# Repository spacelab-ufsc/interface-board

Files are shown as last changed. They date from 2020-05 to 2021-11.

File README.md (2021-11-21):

<h1 align="center">
	Interstage Interface Panels
	<br>
</h1>

<h4 align="center">Interface Panels designed and developed by SpaceLab.</h4>

<p align="center">
	<a href="https://github.com/spacelab-ufsc/spacelab#versioning">
		
	</a>
	<a href="https://github.com/spacelab-ufsc/interface-board/releases">
		
	</a>
	<a href="https://github.com/spacelab-ufsc/interface-board/releases">
		
	</a>
	<a href="https://github.com/spacelab-ufsc/interface-board/commits/master">
		
	</a>
	<a href="https://github.com/spacelab-ufsc/interface-board/issues">
		
	</a>
	<a href="https://github.com/spacelab-ufsc/interface-board/graphs/contributors">
		
	</a>
</p>

<p align="center">
  	<a href="#overview">Overview</a> •
  	<a href="#license">License</a> •
  	<a href="#notes">Notes</a>
</p>

<p align="center">
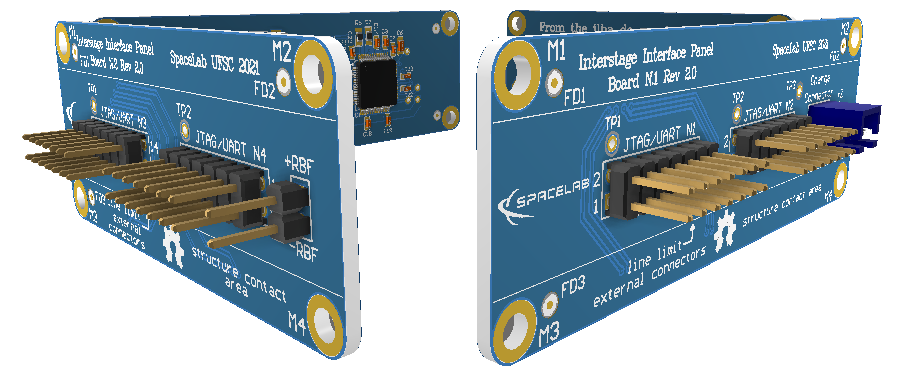
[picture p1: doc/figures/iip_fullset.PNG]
    
</p>

## Overview

Interstage Interface Panels (IIP) are vertical mounted PCBs designed to give external access to the modules inside of a 2U or 3U CubeSat during final assembly, integration and testing. IIP is composed by 4 different boards, the complete set allows for the nanosatellite to be charged, programed and debugged.

## Repository Organization
	- doc: IIP documentation.
	- hardware: IIP hardware project (sources and outputs).

## Releases

The IIP hardware releases are synchronized in order to garantee compatibility. Refer to the [documentation](https://github.com/spacelab-ufsc/interface-board/tree/master/doc) for compatibility notes.

## License

This project is licensed under CERN Open Hardware License (version 2). The documentation is licensed under Creative Commons Attribution-ShareAlike 4.0 International (CC BY-SA 4.0).

## Notes

More info about the SpaceLab: [GitHub](https://github.com/spacelab-ufsc/spacelab) and [Website](https://spacelab.ufsc.br/en/home/).

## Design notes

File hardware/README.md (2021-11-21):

<h1 align="center">
	IIP HARDWARE
	<br>
</h1>

<h4 align="center">Interface panels hardware project (sources and outputs).</h4>

<p align="center">
    <a href="https://github.com/spacelab-ufsc/spacelab#versioning">
        
    </a>
    <a href="https://github.com/spacelab-ufsc/interface-board/releases">
        
    </a>
    <a href="https://github.com/spacelab-ufsc/interface-board/releases">
        
    </a>
    <a href="https://github.com/spacelab-ufsc/interface-board/commits/master">
        
    </a>
    <a href="https://github.com/spacelab-ufsc/interface-board/issues">
        
    </a>
    <a href="">
        
    </a>
    <a href="#license">
        
    </a>
</p>

<p align="center">
  	<a href="#overview">Overview</a> •
  	<a href="#hardware-architecture-diagram">Architecture</a> •
  	<a href="#development">Development</a> •
  	<a href="#version">Version</a> •
  	<a href="#license">License</a> •
  	<a href="#references">References</a>
</p>

## Overview

IIP is composed of 4 pcbs with the main components:

### Nº1 board (1_iip_charge):

<p align="center">
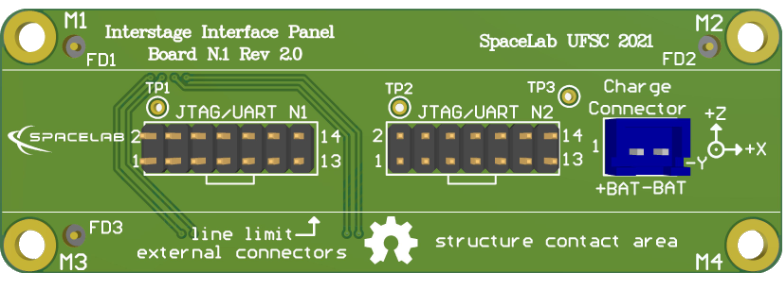
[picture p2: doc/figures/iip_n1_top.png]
	
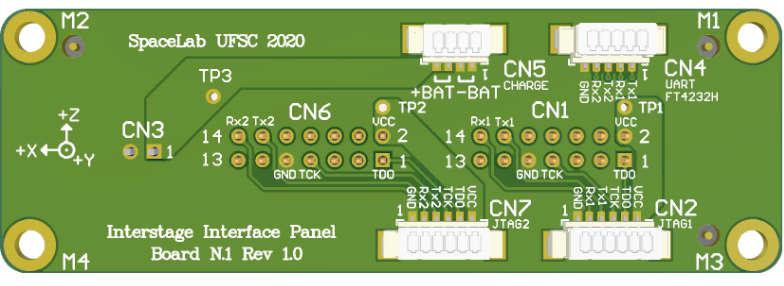
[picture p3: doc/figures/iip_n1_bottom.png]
	
</p>

* Two 7x2 position pin headers for JTAG;
* One JST 2 position header for charging batteries;
* Two 6 pin PicoBlade for internal modules connection;
* One 5 pin PicoBlade for interfacing Nº1 Board to FT4232H present on Nº3 board;
* One 4 pin PicoBlade for battery charge connection to EPS module;

### Nº2 board (2_iip_rbf):

<p align="center">
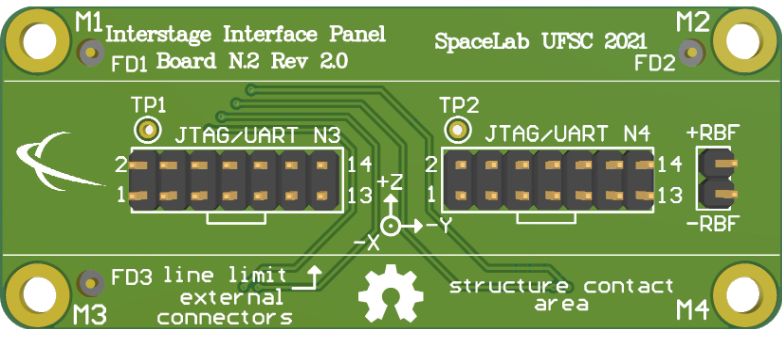
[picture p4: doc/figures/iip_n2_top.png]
	
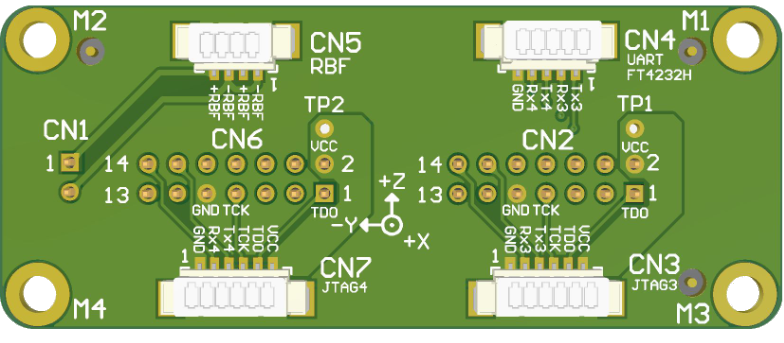
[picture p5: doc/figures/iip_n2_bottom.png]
	
</p>

* Two 7x2 position Pin Headers for JTAG;
* One 2x1 position pin header for Remove Before Flight switch;
* Two 6 pin PicoBlade for internal modules connection;
* One 5 pin PicoBlade for interfacing Nº2 Board to FT4232H present on Nº3 board;
* One 4 pin PicoBlade for RBF switch connection to EPS module;

### Nº3 board (3_iip_QuadUART):

<p align="center">
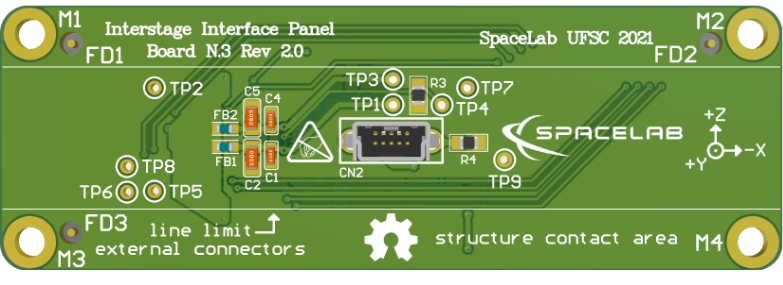
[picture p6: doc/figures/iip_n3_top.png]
	
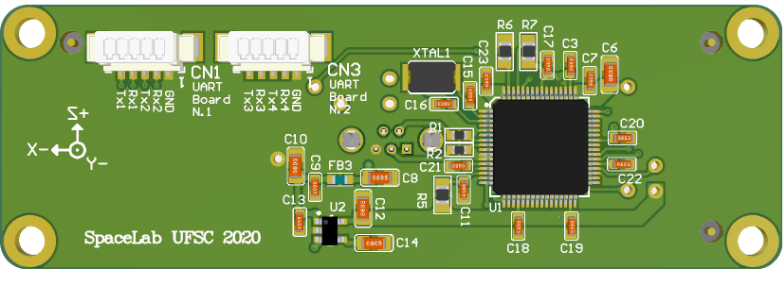
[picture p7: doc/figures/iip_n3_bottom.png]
	
</p>

* One FT4232HL-REEL IC for four quad channel USB to UART conversion;
* One Vertical mini B USB 2.0 port for quad UART channel debbuging;
* Two 5 pin PicoBlade for interfacing boards Nº1 and Nº2;

### Nº4 board (4_iip):

#### Closure variant

<p align="center">
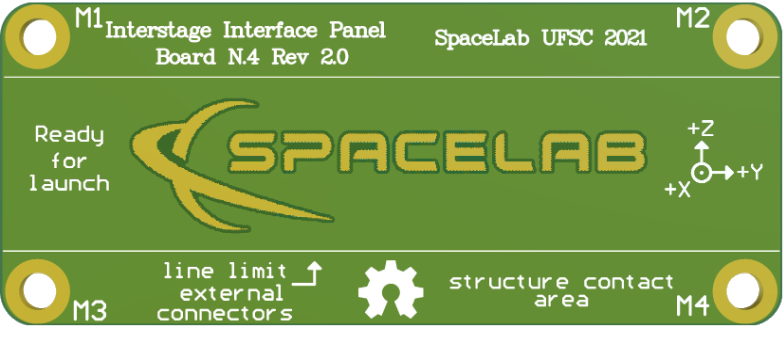
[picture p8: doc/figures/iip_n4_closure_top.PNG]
	
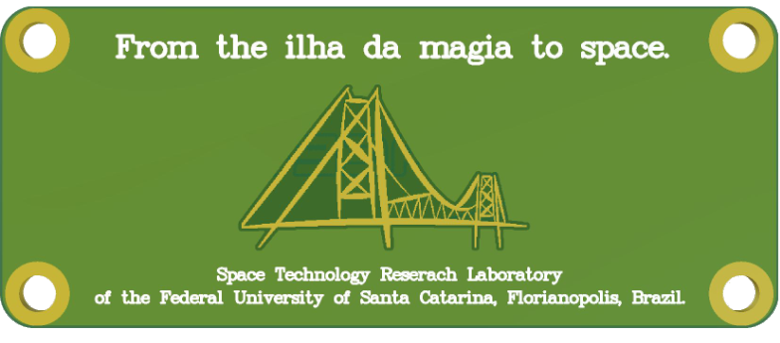
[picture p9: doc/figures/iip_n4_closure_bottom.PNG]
	
</p>

* Empty PCB to close the open side of the 2U/3U CubeSat structure with some easter eggs;

#### Camera variant

<p align="center">
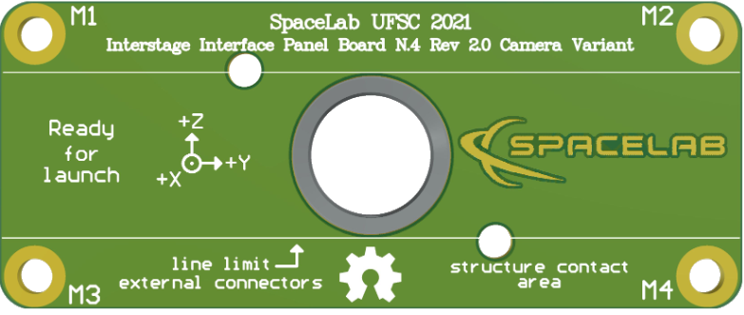
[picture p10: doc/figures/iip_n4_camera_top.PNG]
	
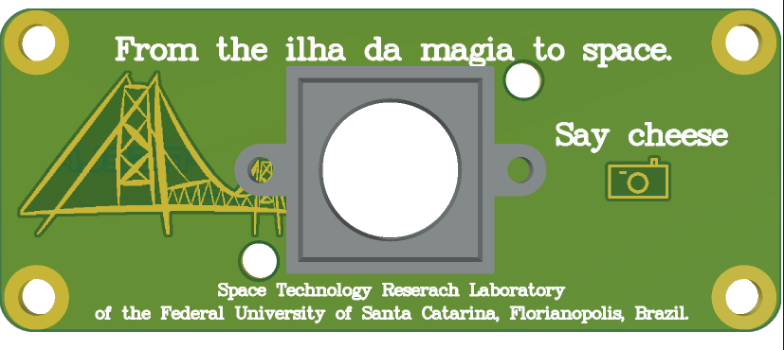
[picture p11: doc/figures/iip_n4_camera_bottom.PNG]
	
</p>

* Hole mount for a M12 lens camera;

> NOTE: The dimensions for the mouting holes follow a old [board breakout design](https://www.google.com/url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), they are still to be tested.

## Hardware architecture diagram

<p align="center">
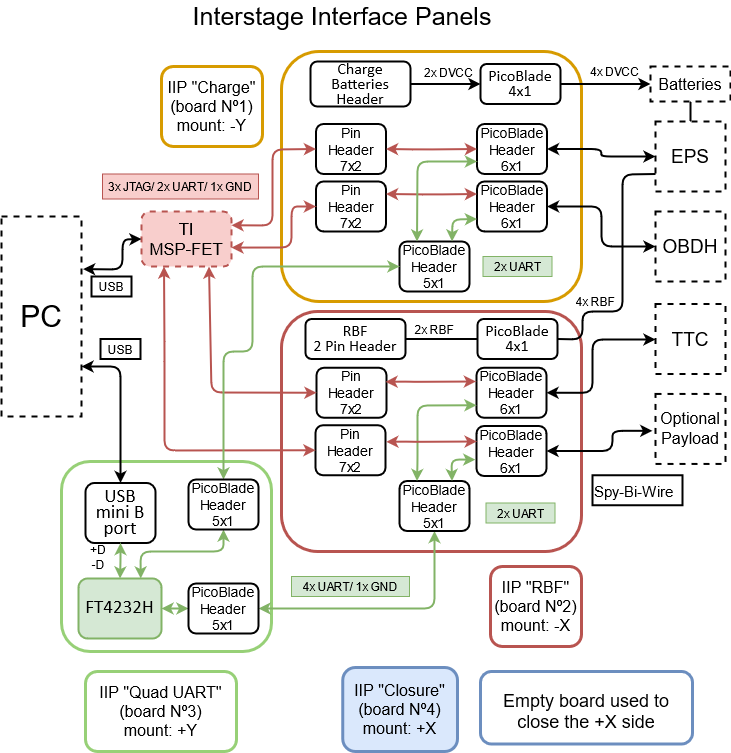
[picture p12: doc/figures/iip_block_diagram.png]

</p>

> This image refers to the v2.0 release.

## Development

#### Manufacture

The folder [fabrication](https://github.com/spacelab-ufsc/interface-board/tree/master/hardware/fabrication) contain 3 "ready to go" files: the gerbers and nc_drills for manufacturing the board, the BOM with all required components, and the pick_place file for automated assembly for each iip board. Additional files are avaliable in the [outputs](https://github.com/spacelab-ufsc/interface-board/tree/master/hardware/outputs) folder, which contain several useful files and documents, such as: 3D models, bill of materials, schematics, layout prints, and draftsman.

## Version

Refer to the [releases](https://github.com/spacelab-ufsc/interface-board/releases) page.

## License

The hardware project of IIP is licensed under CERN Open Hardware License (version 2).

## References

* [NanoUtil Interstage - GOMspace](https://gomspace.com/UserFiles/Subsystems/datasheet/gs-ds-nanoutil-interstage-12.pdf)
* [Quad Serial project from Felipe Navarro](https://github.com/PY1CX/Quad-Serial)
* [FT4232H QUAD HIGH SPEED USB TO MULTIPURPOSE UART/MPSSE IC Datasheet Version 2.6](https://www.ftdichip.com/Support/Documents/DataSheets/ICs/DS_FT4232H)

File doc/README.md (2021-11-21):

<h1 align="center">
	IIP Documentation
	<br>
</h1>

<h4 align="center">Documentation of the Interstage Interface Panels.</h4>

<p align="center">
    <a href="https://github.com/spacelab-ufsc/spacelab#versioning">
        
    </a>
    <a href="https://github.com/spacelab-ufsc/interface-board/releases">
        
    </a>
    <a href="https://github.com/spacelab-ufsc/interface-board/releases">
        
    </a>
    <a href="https://github.com/spacelab-ufsc/interface-board/commits/master">
        
    </a>
    <a href="https://github.com/spacelab-ufsc/interface-board/issues">
    	
	</a>
	<a href="">
		
	</a>
    <a href="#license">
        
    </a>
</p>

<p align="center">
  	<a href="#dependencies">Dependencies</a> •
  	<a href="#generating-the-pdf-file">Generating the PDF file</a> •
  	<a href="#license">License</a> •
  	<a href="#notes">Notes</a>
</p>

## Dependencies

* ```latexmk```
* ```texlive-epstopdf```

## Generating the PDF file

```
make
```

## License

The documentation is licensed under Creative Commons Attribution-ShareAlike 4.0 International (CC BY-SA 4.0).

## Notes

More info about the SpaceLab: [GitHub](https://github.com/spacelab-ufsc/spacelab) and [Website](https://spacelab.ufsc.br/en/home/).

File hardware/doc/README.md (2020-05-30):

### Documentation of the Semi USB variant of Interface Board 2.0

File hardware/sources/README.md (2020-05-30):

### Shematic and PCB files of the Semi USB variant of Interface Board 2.0

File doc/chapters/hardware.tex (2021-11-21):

%
% hardware.tex
%
% Copyright © 2021 by Universidade Federal de Santa Catarina.
%
% Documentation of Interstage Interface Panels
%
% This work is licensed under the Creative Commons Attribution-ShareAlike 4.0
% International License. To view a copy of this license,
% visit http://creativecommons.org/licenses/by-sa/4.0/.
%

%
% \brief Hardware chapter.
%
% \author Yan Castro de Azeredo <yan.azeredo@spacelab.ufsc.br>
%
% \institution Universidade Federal de Santa Catarina (UFSC)
%
% \version 2.0.0
%
% \date 05/07/21 (DD/MM/YY)
%
% \note Credits to Gabriel Mariano Marcelino <gabriel.marcelino@spacelab.ufsc.br> for the creation of the SpaceLab Template
%

\chapter{Hardware} \label{ch:hardware}

IIP is designed to be mouted vertically on the sides of a 2U or 3U CubeSat structure and provide all the minimal features for AIT. In the following sections, the hardware design, external and internal connectors, the FT4232H IC and test points are described in detail. On \autoref{fig:iip-all-boards} is displayed top and bottom PCB prints of all boards.

\begin{figure}[!h]
\centering     %%% not \center
\subfigure[IIP Nº1 "Charge" top]{\label{fig:a}}
\subfigure[IIP Nº1 "Charge" bottom]{\label{fig:b}}
\subfigure[IIP Nº2 "RBF" top]{\label{fig:a}}
\subfigure[IIP Nº2 "RBF" bottom]{\label{fig:b}}
\subfigure[IIP Nº3 "Quad UART" top]{\label{fig:a}}
\subfigure[IIP Nº3 "Quad UART" bottom]{\label{fig:b}}
\subfigure[IIP Nº4 "Closure" variant top]{\label{fig:a}}
\subfigure[IIP Nº4 "Closure" variant bottom]{\label{fig:b}}
\subfigure[IIP Nº4 "Camera" variant top]{\label{fig:a}}
\subfigure[IIP Nº4 "Camera" variant bottom]{\label{fig:b}}
\caption{IIP fullset of boards.}
\label{fig:iip-all-boards}
\end{figure}

\section{Hardware Design}

To be low cost, IIP has the default two layer stackup, HASL finish, 0.3mm minimal hole size, 2.54mm miminal track width and no controled impedance. While for fast USB communication it is recommended a controled impedance of 90 ohms, as exposed in USB Hardware Design Guidelines for FTDI ICs \cite{ftdi-usb-hardware-guidelines}, IIP Nº3 board is not meant to operate with high speed signals. The hightest baund rate for UART log messages for debbuging purposes is expected to be 115200 bps, this parameter is defined for SpaceLab's core modules. Although not a serious concern, the tracks used for the mini USB type B connector to the FT4232H IC were made the shortest possible and most of the guidelines of FTDI were followed.

Components size and positioning were decided for conforming with the CubeSat 2U standard of maximum connector height on the sides of the P-POD structure \cite{p-pod-user-guide} and to a specific project scenario using SpaceLab's core modules for the FloripaSat-2 mission \cite{floripasat2}.

\section{External and internal connectors}

In this section all external and internal connectors are exposed in detail.

\subsection{JTAG/UART Pin Headers}

There are four 14 pin headers (2.54mm pitch) on IIP for JTAG and UART usage, two are present in Nº1 board and the other two in Nº2 board, they can be seem on the two figures \ref{fig:iip-jtag-n1-n2-pin-headers} and \ref{fig:iip-jtag-n3-n4-pin-headers}. These headers were choosen to be used with MSP-FET tool and its standard cable connector. Their pionout is showed on table \ref{tab:jtag-headers-pinout}.

\begin{table}[!h]
    \centering
    \begin{tabular}{cllll}
        \toprule[1.5pt]
        \textit{Pin [A-B]} & \textit{Row A} & \textit{Row B} \\
        \midrule
        1-2                & TDO\_TDI       & VCC\_3V3       \\
        3-4                & -              & -              \\
        5-6                & -              & -              \\
        7-8                & TCK            & -              \\
        9-10               & GND            & -              \\
        11-12              & -              & UART\_TX       \\
        13-14              & -              & UART\_RX       \\
        \bottomrule[1.5pt]
    \end{tabular}
    \caption{JTAG pin headers pinout.}
    \label{tab:jtag-headers-pinout}
\end{table}

\begin{figure}[!ht]
\centering
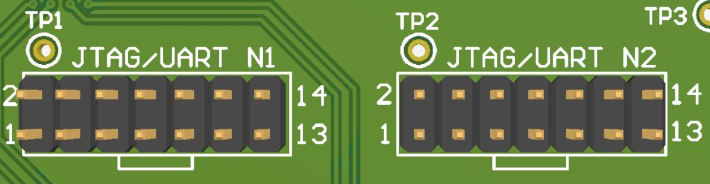
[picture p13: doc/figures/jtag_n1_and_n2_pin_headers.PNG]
    
    \caption{IIP Nº1 JTAG pin headers.}
    \label{fig:iip-jtag-n1-n2-pin-headers}
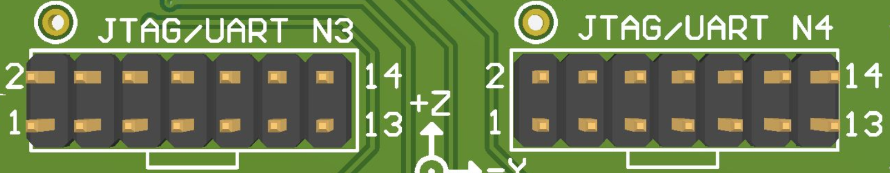
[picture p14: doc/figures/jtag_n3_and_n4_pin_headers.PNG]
    
    \caption{IIP Nº2 JTAG pin headers.}
	\label{fig:iip-jtag-n3-n4-pin-headers}
\end{figure}

Internally these pin headers are interfaced via PicoBlades to be connected to the four modules inside the CubeSat. As can be seen in the block diagram figure \ref{fig:block-diagram} present on the overview chapter, each one of these PicoBlades is assigned to a specific module, they are showed in figures \ref{fig:iip-jtag-n1-n2-picoblades} and \ref{fig:iip-jtag-n3-n4-picoblades}.

\begin{figure}[!ht]
\centering
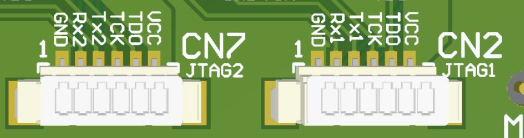
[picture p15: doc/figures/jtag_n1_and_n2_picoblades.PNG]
    
    \caption{IIP Nº1 JTAG PicoBlades.}
    \label{fig:iip-jtag-n1-n2-picoblades}
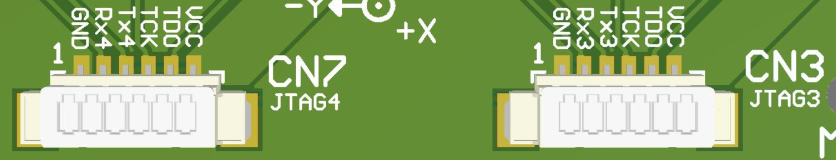
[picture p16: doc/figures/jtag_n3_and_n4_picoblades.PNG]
    
    \caption{IIP Nº2 JTAG PicoBlades.}
	\label{fig:iip-jtag-n3-n4-picoblades}
\end{figure}

\subsection{Charge Header}

On board Nº1 there is a JST XH 2 position header [B2B-XH-A-M(LF)(SN)] for charging batteries of the CubeSat, it can be seen in figure \ref{fig:iip-charge-header}. The component can suport up to 3000mA of current, but in practice it will be used with less than 1500mA. The internal 4 pin PicoBlade connector showed in figure \ref{fig:iip-charge-picoblade} is to be connected to the EPS module to make the interconnection for the JST header. The charge header also provides a detent lock for fastening and avoid mistankenly reverse connection.

\begin{figure}[!ht]
\centering
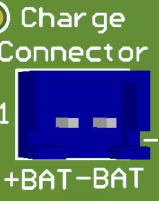
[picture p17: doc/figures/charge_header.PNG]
    
    \caption{IIP Nº1 charge header.}
	\label{fig:iip-charge-header}
\end{figure}

\begin{figure}[!ht]
\centering
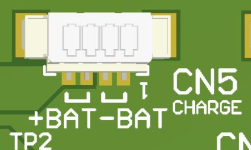
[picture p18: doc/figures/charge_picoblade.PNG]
    
    \caption{IIP Nº1 charge PicoBlade.}
	\label{fig:iip-charge-picoblade}
\end{figure}

\subsection{RBF Pin Header}

The Remove Before Flight pin header is located on board Nº2, see figure \ref{fig:iip-rbf-pin-header}. The choice of its location was according to the CubeSat Design Specification from Cal Poly SLO \cite{cubesat-design-specification} that required the RBF pin to be located on the X plane of the P-POD. This ensures that the CubeSat subsystems will be powered off on test phase using a simple jumper wire conecting the pins, even with kill-swithes already enabled to do this fuctionality by been pressed againts the spring mechanism. The interconnection between the header and the EPS module is done by a internal 4 pin PicoBlade, showed in figure \ref{fig:iip-rbf-picoblade}.

\begin{figure}[!ht]
\centering
    
    \caption{IIP Nº2 RBF pin header.}
	\label{fig:iip-rbf-pin-header}
\end{figure}

\begin{figure}[!ht]
\centering
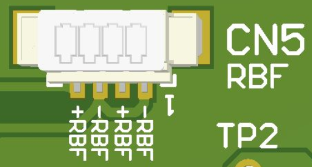
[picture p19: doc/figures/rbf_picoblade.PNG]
    
    \caption{IIP Nº2 RBF PicoBlade.}
	\label{fig:iip-rbf-picoblade}
\end{figure}

\subsection{Mini USB Type B Port}

On Nº3 board there is a vertical mini USB type B 2.0 port (651005136421) to be used for UART debbuging, the connector is seen on figure \ref{fig:iip-usb-port}. This is done though the FT4232HL-REEL IC and its subcircuitry located on the bottom side of the PCB, a better vision is showed on figure \ref{fig:iip-usb-circuitry}. The circuit is self powered by the USB cable, not requiring any external power supply.

There are two internal 5 pin PicoBlade connectors that connects with boards Nº1 and Nº2 to acquire the UART log data from the modules, these components are showed on figure \ref{fig:iip-n3-picoblades}. The other Picoblades that makes this interconnection between interface panels are seen in figures \ref{fig:iip-n1-uart-picoblade} and \ref{fig:iip-n2-uart-picoblade}, for Nº1 and Nº2 boards respectively.

\begin{figure}[!ht]
\centering
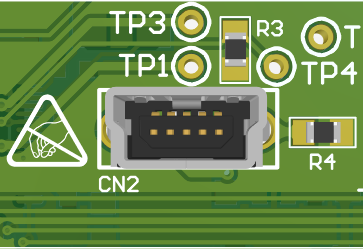
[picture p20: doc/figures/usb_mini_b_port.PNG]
    
    \caption{IIP Nº3 mini USB type B port.}
	\label{fig:iip-usb-port}
\end{figure}

\begin{figure}[!ht]
\centering
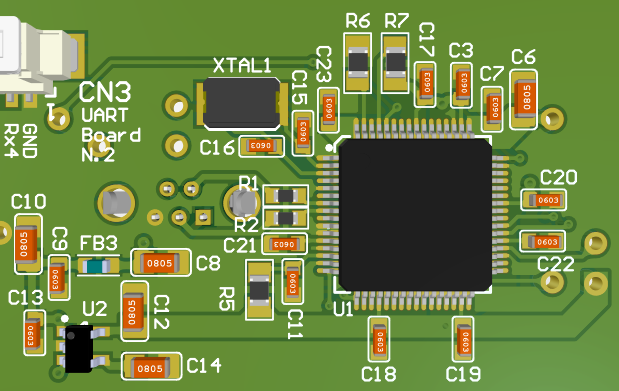
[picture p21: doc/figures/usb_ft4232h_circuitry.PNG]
    
    \caption{IIP Nº3 USB auxiliary circuitry.}
	\label{fig:iip-usb-circuitry}
\end{figure}

\begin{figure}[!ht]
\centering
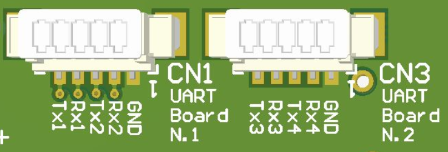
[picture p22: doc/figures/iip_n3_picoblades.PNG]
    
    \caption{IIP Nº3 UART PicoBlades.}
    \label{fig:iip-n3-picoblades}
\end{figure}

\begin{figure}[!ht]
\centering
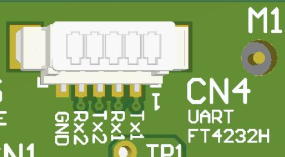
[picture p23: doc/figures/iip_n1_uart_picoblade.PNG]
    
    \caption{IIP Nº1 UART PicoBlade.}
    \label{fig:iip-n1-uart-picoblade}
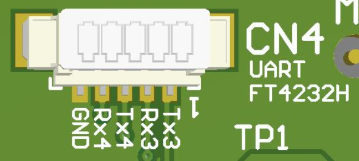
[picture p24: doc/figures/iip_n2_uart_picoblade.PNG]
     
    \caption{IIP Nº2 UART PicoBlade.}
    \label{fig:iip-n2-uart-picoblade}
\end{figure}

\section{FT4232H IC}

For UART to USB conversion the FT4232HL-REEL IC from FTDI \cite{ftdi-ft4232h-datasheet} was chossen for enabling the debbuging though log messages for 4 independent modules. The REEL form factor was decided to be easier to be soldered manually if necessary. The IC gives flexibility to have an integrated UART to USB conversion in the inferface of IIP, not needing the use of a external device like the FT232. The component and its auxiliary subcircuitry can be seen on figure \ref{fig:iip-usb-circuitry}.

\section{Test Points}

On the three boards of IIP there are some test points that can be easily acessed from the front side of the panels. Others that are present on the "structure contact area" will not be available when the interface is assembled on the 2U CubeSat structure, see the PCBs top and bottom prints on figures figures \ref{fig:iip-all-boards-top-bottom-1} to \ref{fig:iip-all-boards-top-bottom-2}. The reason for this is that the metal frame of the structure will be at the front blocking the access, referer to chapter \ref{ch:board-assembly} for more details. Next is presented the tables of the test points labels and their description of the boards Nº1: \ref{tab:iip-n1-testpoints}, Nº2: \ref{tab:iip-n2-testpoints} and Nº3: \ref{tab:iip-n3-testpoints}.

\begin{table}[!h]
    \centering
    \begin{tabular}{cllll}
        \toprule[1.5pt]
        \textit{Label} & \textit{Description} \\
        \midrule
        TP1                & JTAG 1 3V3 power\\
        TP2                & JTAG 2 3V3 power\\
        TP3                & Battery charge header positive polarity \\
        \bottomrule[1.5pt]
    \end{tabular}
    \caption{IIP Nº1 board test points.}
    \label{tab:iip-n1-testpoints}
\end{table}

\begin{table}[!h]
    \centering
    \begin{tabular}{cllll}
        \toprule[1.5pt]
        \textit{Label} & \textit{Description} \\
        \midrule
        TP1                & JTAG 3 3V3 power\\
        TP2                & JTAG 4 3V3 power\\
        \bottomrule[1.5pt]
    \end{tabular}
    \caption{IIP Nº2 board test points.}
    \label{tab:iip-n2-testpoints}
\end{table}

\begin{table}[!h]
    \centering
    \begin{tabular}{cllll}
        \toprule[1.5pt]
        \textit{Label} & \textit{Description} \\
        \midrule
        TP1                & (VPLL) 3V3 FT4232H power input. \\
        TP2                & (VREGOUT) 1V8 FT4232H internal power output. \\
        TP3                & (VPHY) 3V3 FT4232H power input. \\
        TP4                & (REF) Current reference for FT4232H. \\
        TP5                & (RESET\#) Reset input for FT4232H. \\
        TP6                & (VCCIO) I/O interface 3V3 power supply input. \\
        TP7                & (PWREN\#) Active low power-enable output. \\
        TP8                & (SUSPEND\#) Active low when USB is in suspend mode. \\
        TP9                & (GND) 0V ground input for FT4232H.\\
        \bottomrule[1.5pt]
    \end{tabular}
    \caption{IIP Nº3 board test points.}
    \label{tab:iip-n3-testpoints}
\end{table}

\section{M12 Camera Lens Mount}

On IIP Nº4 variant camera board has a center hole to serve as an opening for an M12 camera lens, the other two holes are for mouting the ArduCam MT9D111 rev.B. breakout board, as seen in \autoref{fig:arducam}. On \autoref{fig:n4-mec} is displayed the PCB mouting hole distances and sizes for the camera.

\begin{figure}[!ht]
  \centering
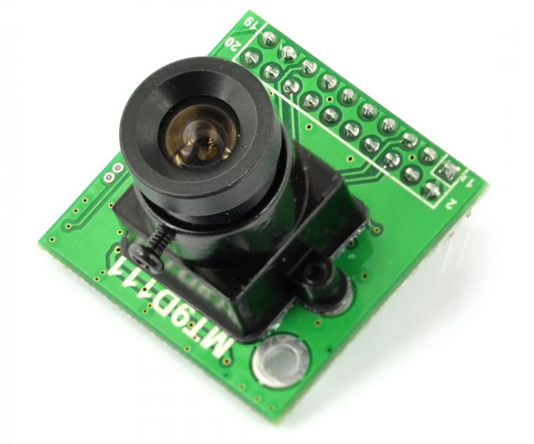
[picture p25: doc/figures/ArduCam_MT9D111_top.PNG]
    \subfigure[]{\label{fig:a}}
    \subfigure[]{\label{fig:b}}
    \caption{ArduCam MT9D111 rev.B.}
    \label{fig:arducam}
\end{figure}

\begin{figure}[!ht]
\centering
    
    \caption{IIP Nº4 Camera variant mechanical dimensions.}
    \label{fig:n4-mec}
\end{figure}

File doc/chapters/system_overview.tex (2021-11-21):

%
% system_overview.tex
%
% Copyright © 2021 by Universidade Federal de Santa Catarina.
%
% Documentation of Interstage Interface Panels
%
% This work is licensed under the Creative Commons Attribution-ShareAlike 4.0
% International License. To view a copy of this license,
% visit http://creativecommons.org/licenses/by-sa/4.0/.
%

%
% \brief System overview chapter.
%
% \author Yan Castro de Azeredo <yan.azeredo@spacelab.ufsc.br>
%
% \institution Universidade Federal de Santa Catarina (UFSC)
%
% \version 2.0.0
%
% \date 05/07/21 (DD/MM/YY)
%
% \note Credits to Gabriel Mariano Marcelino <gabriel.marcelino@spacelab.ufsc.br> for the creation of the SpaceLab Template
%

\chapter{System Overview} \label{ch:system-overview}

\section{Block Diagram}

On figure \ref{fig:block-diagram} is displayed the full system block diagram with external devices such as the MSP-FET and a personal computer (PC) during normal usage of IIP.
Up to four CubeSat modules can be acessed from its interfaces, been though the pin headers or the USB port. 
For the FloripaSat-2 mission, the core modules (EPS, OBDH and TTC) and a optional payload are already represented with their respective interconnections.
These connections are done internally with PicoBlade connectors, which are compatible with the mission's modules. 
The fourth board, labeled IIP Nº4, has two variants, one only serves as a closure for the side panel of the CubeSat structure, while the other features a central hole for a M12 camera lens and mouting holes for a breakout board.

\begin{figure}[!ht]
    \begin{center}
        
        \caption{IIP hardware block diagram.}
        \label{fig:block-diagram}
    \end{center}
\end{figure}

\section{Board Numeration}

Since the IIP is divided up to 4 boards, a numeration was adopted for better refering each PCB on this document. The numeration followed the criteria of the mounting sides determined by the cartesian axis of a Poly Picosatellite Orbital Deployer (P-POD) \cite{p-pod-user-guide}. Starting the numeration "Nº1" from the referenced -Y plane, the other boards are classified clock-wise that can be found on figure \ref{fig:iip-numeration}, each labeled axis can be better seen on \autoref{fig:iip-all-boards}. The boards also received names with their unique functionality, Nº1 board is also called "IIP Charge", Nº2 board the "IIP RBF", Nº3 board the "IIP Quad UART" and Nº4 board the "Closure" or "Camera" depending on its variant, these nominations are present on the PCBs source files.

\begin{figure}[!ht]
  \centering
    
    \caption{IIP Nº1 board.}
    
    \caption{IIP Nº2 board.}
    
    \caption{IIP Nº3 board.}
    
    \caption{IIP Nº4 closure variant board.}
    
    \caption{IIP Nº4 camera variant board.}
    \label{fig:iip-numeration}
\end{figure}

\section{Board Dimensions}

IIP is to be mouted vertically inside on the sides of a 2U/3U CubeSat structure, this makes de Nº1 and Nº3 boards having the same PCB dimensions because they are on the same X plane of reference, see figure \ref{fig:iip-n1-n3-dimensions}. 
The Nº2 and Nº4 board dimensions can be seen in figure \ref{fig:iip-n2-n4-dimensions}.
The "structure contact area" is the place where the metal frame of the CubeSat structure will be overlapping.
All other measurements important to integration and assembly are present in the draftsman PDF documents of each board are present on GitHub\cite{iip-draftsman}.
Refer to \autoref{sec:integration} for more details on mechenical integration of IIP.

\begin{figure}[!ht]
  \centering
    
    \caption{IIP Nº1 and Nº3 top dimensions.}
    \label{fig:iip-n1-n3-dimensions}
    
    \caption{IIP Nº2 and Nº4 board top dimensions.}
    \label{fig:iip-n2-n4-dimensions}
\end{figure}

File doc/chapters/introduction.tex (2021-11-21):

%
% introduction.tex
%
% Copyright © 2021 by Universidade Federal de Santa Catarina.
%
% Documentation of Interstage Interface Panels
%
% This work is licensed under the Creative Commons Attribution-ShareAlike 4.0
% International License. To view a copy of this license,
% visit http://creativecommons.org/licenses/by-sa/4.0/.
%

%
% \brief Introduction file.
%
% \author Yan Castro de Azeredo <yan.azeredo@spacelab.ufsc.br>
%
% \institution Universidade Federal de Santa Catarina (UFSC)
%
% \version 2.0.0
%
% \date 05/07/21 (DD/MM/YY)
%
% \note Credits to Gabriel Mariano Marcelino <gabriel.marcelino@spacelab.ufsc.br> for the creation of the SpaceLab Template
%

\chapter{Introduction} \label{ch:introduction}

The Interstage Interface Panels (IIP) are four vertical internally mounted Printed Circuit Boards (PCB\nomenclature{\textbf{PCB}}{\textit{Printed Circuit Board.}}) designed 
to give external access up to four modules inside of a 2U or 3U CubeSat during 
final assembly, integration and testing (AIT\nomenclature{\textbf{AIT}}{\textit{Assembly, integration and testing.}}) before launch.
The complete set of the boards allow the nanosatellite to be charged, programed and debugged. 
The usage of this project is taking into account the use of a MSP-FET: MSP430 Flash Emulation Tool from Texas Instruments for JTAG programing and debugging, UART debugging through a mini USB type B port interfacing the FT4232H USB bridge Integrated Circuit (IC\nomenclature{\textbf{IC}}{\textit{Integrated Circuit.}}) from FTDI, a JST XH header for charging internal batteries and a Remove Before Flight (RBF\nomenclature{\textbf{RBF}}{\textit{Remove Before Flight.}}) pin header.
One board variant features an opening for a M12 camera lens.  
These tools and methodology for testing are definied directly from the project main use on the FloripaSat-2 mission \cite{floripasat2} been done by SpaceLab UFSC.

\begin{figure}[!ht]
    \centering
    
    \caption{Interstage Interface Panel boards.}
    \label{iip-fullset}
  \end{figure}

All the project, source and documentation files are available freely on a GitHub repository \cite{interface-board-repo}.

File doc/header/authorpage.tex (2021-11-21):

%
% authorpage.tex
%
% Copyright © 2021 by Universidade Federal de Santa Catarina.
%
% Documentation of Interstage Interface Panels
%
% This work is licensed under the Creative Commons Attribution-ShareAlike 4.0
% International License. To view a copy of this license,
% visit http://creativecommons.org/licenses/by-sa/4.0/.
%

%
% \brief Author page.
%
% \author Yan Castro de Azeredo <yan.azeredo@spacelab.ufsc.br>
%
% \institution Universidade Federal de Santa Catarina (UFSC)
%
% \version 2.0.0
%
% \date 05/07/21 (DD/MM/YY)
%
% \note Credits to Gabriel Mariano Marcelino <gabriel.marcelino@spacelab.ufsc.br> for the creation of the SpaceLab Template
%

\thispagestyle{empty}

\begin{center}

\textbf{\thetitle}

\textit{July, 2021}

\vspace{1cm}

\textbf{Project Chief:}

Eduardo Augusto Bezerra

\vspace{1cm}

\textbf{Authors:}

Yan Castro de Azeredo <\href{mailto:yan.azeredo@spacelab.ufsc.br}{yan.azeredo@spacelab.ufsc.br}>\\
% Author 2 \\
% Author 3 \\

\vspace{1cm}

\textbf{Contributing Authors:}

André Martins Pio de Mattos <\href{mailto:andre.mattos@spacelab.ufsc.br}{andre.mattos@spacelab.ufsc.br}>\\
Gabriel Mariano Marcelino <\href{mailto:gabriel.marcelino@spacelab.ufsc.br}{gabriel.marcelino@spacelab.ufsc.br}>\\
% Author 3 \\

\vspace{1cm}

\textbf{Revision Control:}

\end{center}

\begin{table}[!ht]
    \begin{center}
        \begin{tabular}{cL{5cm}L{5.5cm}C{2cm}}
            \toprule[1.5pt]
            \textbf{Version} & \textbf{Author} & \textbf{Changes}    & \textbf{Date} \\
            \midrule
            0.1     & Yan C. de Azeredo    & Document creation   & 07/2020    \\
            1.0     & Yan C. de Azeredo    & First release       & 12/2020    \\
            2.0     & Yan C. de Azeredo    & Adding fourth interface board to project & 07/2021\\
                    &                          &                     &            \\
                    &                          &                     &            \\
            \bottomrule[1.5pt]
        \end{tabular}
    \end{center}
\end{table}

\vfill

\begin{figure}[!h]
	\begin{center}
		
	\end{center}
\end{figure}

\textcopyright\  2021 by Universidade Federal de Santa Catarina. Interstage Interface Panels. This work is licensed under the Creative Commons Attribution-ShareAlike 4.0 International License. To view a copy of this license, visit \href{http://creativecommons.org/licenses/by-sa/4.0/}{http://creativecommons.org/licenses/by-sa/4.0/}.

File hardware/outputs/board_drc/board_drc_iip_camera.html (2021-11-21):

Altium

# Design Rule Verification Report

Date: | | 7/4/2021
Time: | | 6:49:42 PM
Elapsed Time: | | 00:00:01
Filename: | | C:\Users\Yan Azeredo\Desktop\SpaceLab\interface-board\hardware\sources\4_iip_camera.PcbDoc

Warnings: | | 0
Rule Violations: | | 9

## Summary

Warnings | Count
Total | 0

Rule Violations | Count
Clearance Constraint (Gap=0.254mm) (All),(All) | 0
Clearance Constraint (Gap=0.254mm) (All),(All) | 0
Short-Circuit Constraint (Allowed=No) (All),(All) | 0
Un-Routed Net Constraint ( (All) ) | 0
Modified Polygon (Allow modified: No), (Allow shelved: No) | 0
Width Constraint (Min=0.254mm) (Max=0.254mm) (Preferred=0.254mm) (All) | 0
Width Constraint (Min=0.127mm) (Max=0.508mm) (Preferred=0.254mm) (All) | 0
Power Plane Connect Rule(Relief Connect )(Expansion=0.508mm) (Conductor Width=0.254mm) (Air Gap=0.254mm) (Entries=4) (All) | 0
Minimum Annular Ring (Minimum=0.254mm) (All) | 0
Minimum Annular Ring (Minimum=0.13mm) (All) | 0
Hole Size Constraint (Min=0.025mm) (Max=2.54mm) (All) | 0
Hole Size Constraint (Min=0.3mm) (Max=6.3mm) (All) | 1
Hole To Hole Clearance (Gap=0.54mm) (All),(All) | 0
Hole To Hole Clearance (Gap=0.254mm) (All),(All) | 0
Minimum Solder Mask Sliver (Gap=0.254mm) (All),(All) | 0
Minimum Solder Mask Sliver (Gap=0.2mm) (All),(All) | 3
Silk To Solder Mask (Clearance=0.15mm) (IsPad),(All) | 0
Silk To Solder Mask (Clearance=0.254mm) (IsPad),(All) | 0
Silk to Silk (Clearance=0.254mm) (All),(All) | 0
Net Antennae (Tolerance=0mm) (All) | 0
Board Clearance Constraint (Gap=0mm) (All) | 5
Board Clearance Constraint (Gap=0mm) (All) | 0
Height Constraint (Min=0mm) (Max=25.4mm) (Prefered=12.7mm) (All) | 0
Total | 9

Hole Size Constraint (Min=0.3mm) (Max=6.3mm) (All)

Hole Size Constraint: (14.5mm > 6.3mm) Pad Free-0(33.787mm,13.987mm) on Multi-Layer Actual Hole Size = 14.5mm

Back to top

Minimum Solder Mask Sliver (Gap=0.2mm) (All),(All)

Minimum Solder Mask Sliver Constraint: (0.194mm < 0.2mm) Between Arc (12.4mm,12.9mm) on Bottom Solder And Track (9.9mm,11.671mm)(14.862mm,11.671mm) on Bottom Solder [Bottom Solder] Mask Sliver [0.194mm]

Minimum Solder Mask Sliver Constraint: (0.143mm < 0.2mm) Between Track (10.8mm,14.4mm)(10.8mm,14.9mm) on Bottom Solder And Track (11.197mm,14.9mm)(11.2mm,14.897mm) on Bottom Solder [Bottom Solder] Mask Sliver [0.143mm]

Minimum Solder Mask Sliver Constraint: (0.146mm < 0.2mm) Between Track (10.8mm,14.4mm)(10.8mm,14.9mm) on Bottom Solder And Track (11.2mm,14.338mm)(11.2mm,14.897mm) on Bottom Solder [Bottom Solder] Mask Sliver [0.146mm]

Back to top

Board Clearance Constraint (Gap=0mm) (All)

Board Outline Clearance(Outline Edge): (Collision < 0.2mm) Between Board Edge And Text "'.Layer_Name'" (177.571mm,-11.538mm) on Bottom Layer

Board Outline Clearance(Outline Edge): (Collision < 0.2mm) Between Board Edge And Text "'.Layer_Name'" (177.571mm,-11.538mm) on Bottom Overlay

Board Outline Clearance(Outline Edge): (Collision < 0.2mm) Between Board Edge And Text "'.Layer_Name'" (177.571mm,-11.538mm) on Top Layer

Board Outline Clearance(Outline Edge): (Collision < 0.2mm) Between Board Edge And Text "'.Layer_Name'" (177.571mm,-11.538mm) on Top Overlay

Board Outline Clearance(Outline Edge): (0.1mm < 0.2mm) Between Board Edge And Text "Space Technology Reserach Laboratory of the Federal University of Santa Catarina, Florianopolis, Brazil." (61mm,0.1mm) on Bottom Overlay

Back to top

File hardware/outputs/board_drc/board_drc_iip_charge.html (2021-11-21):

Altium

# Design Rule Verification Report

Date: | | 6/29/2021
Time: | | 12:14:08 AM
Elapsed Time: | | 00:00:01
Filename: | | C:\Users\Yan Azeredo\Desktop\SpaceLab\interface-board\hardware\sources\1_IIP_Charge.PcbDoc

Warnings: | | 0
Rule Violations: | | 4

## Summary

Warnings | Count
Total | 0

Rule Violations | Count
Clearance Constraint (Gap=0.254mm) (All),(All) | 0
Clearance Constraint (Gap=0.254mm) (All),(All) | 0
Short-Circuit Constraint (Allowed=No) (All),(All) | 0
Un-Routed Net Constraint ( (All) ) | 0
Modified Polygon (Allow modified: No), (Allow shelved: No) | 0
Width Constraint (Min=0.127mm) (Max=0.508mm) (Preferred=0.254mm) (All) | 0
Width Constraint (Min=0.254mm) (Max=0.254mm) (Preferred=0.254mm) (All) | 0
Power Plane Connect Rule(Relief Connect )(Expansion=0.508mm) (Conductor Width=0.254mm) (Air Gap=0.254mm) (Entries=4) (All) | 0
Minimum Annular Ring (Minimum=0.13mm) (All) | 0
Minimum Annular Ring (Minimum=0.254mm) (All) | 0
Hole Size Constraint (Min=0.3mm) (Max=6.3mm) (All) | 0
Hole Size Constraint (Min=0.025mm) (Max=2.54mm) (All) | 0
Hole To Hole Clearance (Gap=0.54mm) (All),(All) | 0
Hole To Hole Clearance (Gap=0.254mm) (All),(All) | 0
Minimum Solder Mask Sliver (Gap=0.2mm) (All),(All) | 0
Minimum Solder Mask Sliver (Gap=0.254mm) (All),(All) | 0
Silk To Solder Mask (Clearance=0.254mm) (IsPad),(All) | 0
Silk To Solder Mask (Clearance=0.15mm) (IsPad),(All) | 0
Silk to Silk (Clearance=0.254mm) (All),(All) | 0
Net Antennae (Tolerance=0mm) (All) | 0
Board Clearance Constraint (Gap=0mm) (All) | 0
Board Clearance Constraint (Gap=0mm) (All) | 4
Height Constraint (Min=0mm) (Max=25.4mm) (Prefered=12.7mm) (All) | 0
Total | 4

Board Clearance Constraint (Gap=0mm) (All)

Board Outline Clearance(Outline Edge): (Collision < 0.2mm) Between Board Edge And Text "'.Layer_Name'" (177.571mm,-11.538mm) on Bottom Layer

Board Outline Clearance(Outline Edge): (Collision < 0.2mm) Between Board Edge And Text "'.Layer_Name'" (177.571mm,-11.538mm) on Bottom Overlay

Board Outline Clearance(Outline Edge): (Collision < 0.2mm) Between Board Edge And Text "'.Layer_Name'" (177.571mm,-11.538mm) on Top Layer

Board Outline Clearance(Outline Edge): (Collision < 0.2mm) Between Board Edge And Text "'.Layer_Name'" (177.571mm,-11.538mm) on Top Overlay

Back to top

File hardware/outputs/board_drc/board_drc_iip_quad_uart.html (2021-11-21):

Altium

# Design Rule Verification Report

Date: | | 7/1/2021
Time: | | 12:09:49 AM
Elapsed Time: | | 00:00:02
Filename: | | C:\Users\Yan Azeredo\Desktop\SpaceLab\interface-board\hardware\sources\3_iip_quad_uart.PcbDoc

Warnings: | | 0
Rule Violations: | | 4
Waived Violations: | | 1

## Summary

Warnings | Count
Total | 0

Rule Violations | Count
Clearance Constraint (Gap=0.254mm) (All),(All) | 0
Clearance Constraint (Gap=0.254mm) (All),(All) | 0
Short-Circuit Constraint (Allowed=No) (All),(All) | 0
Un-Routed Net Constraint ( (All) ) | 0
Modified Polygon (Allow modified: No), (Allow shelved: No) | 0
Width Constraint (Min=0.127mm) (Max=0.508mm) (Preferred=0.254mm) (All) | 0
Width Constraint (Min=0.254mm) (Max=0.254mm) (Preferred=0.254mm) (All) | 0
Power Plane Connect Rule(Relief Connect )(Expansion=0.508mm) (Conductor Width=0.254mm) (Air Gap=0.254mm) (Entries=4) (All) | 0
Minimum Annular Ring (Minimum=0.13mm) (All) | 0
Minimum Annular Ring (Minimum=0.254mm) (All) | 0
Hole Size Constraint (Min=0.025mm) (Max=2.54mm) (All) | 0
Hole Size Constraint (Min=0.3mm) (Max=6.3mm) (All) | 0
Hole To Hole Clearance (Gap=0.54mm) (All),(All) | 0
Hole To Hole Clearance (Gap=0.254mm) (All),(All) | 0
Minimum Solder Mask Sliver (Gap=0mm) (All),(All) | 0
Minimum Solder Mask Sliver (Gap=0.254mm) (All),(All) | 0
Minimum Solder Mask Sliver (Gap=0.2mm) (All),(All) | 0
Silk To Solder Mask (Clearance=0.254mm) (IsPad),(All) | 0
Silk To Solder Mask (Clearance=0.15mm) (IsPad),(All) | 0
Silk To Solder Mask (Clearance=0mm) (IsPad),(All) | 0
Silk to Silk (Clearance=0.254mm) (All),(All) | 0
Net Antennae (Tolerance=0mm) (All) | 0
Board Clearance Constraint (Gap=0mm) (All) | 0
Board Clearance Constraint (Gap=0mm) (All) | 4
Height Constraint (Min=0mm) (Max=25.4mm) (Prefered=12.7mm) (All) | 0
Total | 4

Waived Violations | Count
Un-Routed Net Constraint ( (All) ) | 1
Total | 1

## Rule Violations

Board Clearance Constraint (Gap=0mm) (All)

Board Outline Clearance(Outline Edge): (Collision < 0.2mm) Between Board Edge And Text "'.Layer_Name'" (177.571mm,-11.538mm) on Bottom Layer

Board Outline Clearance(Outline Edge): (Collision < 0.2mm) Between Board Edge And Text "'.Layer_Name'" (177.571mm,-11.538mm) on Bottom Overlay

Board Outline Clearance(Outline Edge): (Collision < 0.2mm) Between Board Edge And Text "'.Layer_Name'" (177.571mm,-11.538mm) on Top Layer

Board Outline Clearance(Outline Edge): (Collision < 0.2mm) Between Board Edge And Text "'.Layer_Name'" (177.571mm,-11.538mm) on Top Overlay

Back to top

## Waived Violations

Un-Routed Net Constraint ( (All) )

Un-Routed Net Constraint: Net USB_SHIELD Between Pad CN2-0(37.05mm,13.675mm) on Multi-Layer And Pad CN2-0(45.45mm,13.675mm) on Multi-Layer
Waived by Yan Azeredo at 7/19/2020 12:04:10 AM
One side of the housing is already routed

Back to top

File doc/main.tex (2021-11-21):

%
% main.tex
%
% Copyright © 2021 by Universidade Federal de Santa Catarina.
%
% Documentation of Interstage Interface Panels
%
% This work is licensed under the Creative Commons Attribution-ShareAlike 4.0
% International License. To view a copy of this license,
% visit http://creativecommons.org/licenses/by-sa/4.0/.
%

%
% \brief Main file.
%
% \author Yan Castro de Azeredo <yan.azeredo@spacelab.ufsc.br>
%
% \institution Universidade Federal de Santa Catarina (UFSC)
%
% \version 2.0.0
%
% \date 05/07/21 (DD/MM/YY)
%
% \note Credits to Gabriel Mariano Marcelino <gabriel.marcelino@spacelab.ufsc.br> for the creation of the SpaceLab Template
%

\documentclass[a4paper,12pt]{book}

\usepackage{spacelab_book}

\title{Documentation of Interstage Interface Panels}
\author{SpaceLab}
\date{\today}

% File metadata
\hypersetup
{
    pdfauthor   = {SpaceLab},
    pdfsubject  = {\thetitle},
    pdftitle    = {\thetitle},
    pdfkeywords = {Nanosatellites, CubeSat interfaces, AIT}
}

\begin{document}

    \pagenumbering{roman}
    \setcounter{page}{1}

    \input{header/titlepage}
    \cleardoublepage
    \input{header/authorpage}
    \cleardoublepage

    \listoffigures
    \addcontentsline{toc}{chapter}{List of Figures}

    \listoftables
    \addcontentsline{toc}{chapter}{List of Tables}

    \printnomenclature
    \addcontentsline{toc}{chapter}{Nomenclature}

    \tableofcontents
    \cleardoublepage
    
    \pagenumbering{arabic}
    \setcounter{page}{1}

    \input{chapters/introduction}
    \input{chapters/system_overview}
    \input{chapters/hardware}
    \input{chapters/board_assembly}
    \input{chapters/usage_instructions}
    \input{chapters/references}
    \input{appendices/appendices}

\end{document}

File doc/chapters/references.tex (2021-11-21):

%
% references.tex
%
% Copyright © 2021 by Universidade Federal de Santa Catarina.
%
% Documentation of Interstage Interface Panels
%
% This work is licensed under the Creative Commons Attribution-ShareAlike 4.0
% International License. To view a copy of this license,
% visit http://creativecommons.org/licenses/by-sa/4.0/.
%

%
% \brief References chapter.
%
% \author Yan Castro de Azeredo <yan.azeredo@spacelab.ufsc.br>
%
% \institution Universidade Federal de Santa Catarina (UFSC)
%
% \version 2.0.0
%
% \date 05/07/21 (DD/MM/YY)
%
% \note Credits to Gabriel Mariano Marcelino <gabriel.marcelino@spacelab.ufsc.br> for the creation of the SpaceLab Template
%

\bibliography{references/interface-board-repo,references/p-pod-user-guide,references/floripasat2,references/ftdi-usb-hardware-guidelines,references/cubesat-design-specification,references/ftdi-ft4232h-datasheet,references/iip-draftsman}

\addcontentsline{toc}{chapter}{References}

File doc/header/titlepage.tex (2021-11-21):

%
% titlepage.tex
%
% Copyright © 2021 by Universidade Federal de Santa Catarina.
%
% Documentation of Interstage Interface Panels
%
% This work is licensed under the Creative Commons Attribution-ShareAlike 4.0
% International License. To view a copy of this license,
% visit http://creativecommons.org/licenses/by-sa/4.0/.
%

%
% \brief Title page.
%
% \author Yan Castro de Azeredo <yan.azeredo@spacelab.ufsc.br>
%
% \institution Universidade Federal de Santa Catarina (UFSC)
%
% \version 2.0.0
%
% \date 05/07/21 (DD/MM/YY)
%
% \note Credits to Gabriel Mariano Marcelino <gabriel.marcelino@spacelab.ufsc.br> for the creation of the SpaceLab Template
%

\begin{titlepage}

\thispagestyle{empty}

\begin{flushleft}
SLB-IIP-DOC-v2.0
\end{flushleft}

\begin{figure}[!ht]
    \begin{flushleft}
        
    \end{flushleft}
\end{figure}

\begin{flushleft}
\Huge{\textbf{\thetitle}}
\rule[0pt]{\textwidth}{5pt}
\end{flushleft}

\vspace{0.2cm}

\begin{flushleft}
\textit{Documentation of Interstage Interface Panels} \\
\textit{SpaceLab, Universidade Federal de Santa Catarina, Florianópolis - Brazil}
\end{flushleft}

\vfill
\vfill

\begin{flushright}
July 2021
\end{flushright}

\end{titlepage}

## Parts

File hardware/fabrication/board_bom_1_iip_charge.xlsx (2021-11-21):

 |  |  | Bill of Materials
 |  |  | Source Data From: | 1_iip_charge.PrjPCB
 |  |  | Project: | 1_iip_charge.PrjPCB
 |  |  | Variant: | None
 |  |  | Project Code: | IIPN1
 |  |  | Report Date: | 6/28/2021 | 10:21:38 PM
 |  |  | Print Date: | 2021-06-28 | 22:21:42
# | Designator | Quantity | #Column Name Error:Manufacturer | Manufacturer Part Number | #Column Name Error:Partnumber | Description | #Column Name Error:Package | #Column Name Error:Footprint | #Column Name Error:Mount | Fitted
1 | CN2, CN7 | 2 |  | 53398-0671 |  | 1.25mm Pitch PicoBlade™ Header, Surface Mount, Vertical, 6 Circuits |  |  |  | Fitted
2 | CN1, CN6 | 2 |  | M20-9980745 |  | Headers & Wire Housings 07+07 DIL VERTICAL PIN HEADER GOLD HT |  |  |  | Fitted
3 | CN5 | 1 |  | 53398-0471 |  | Connector Header Surface Mount 4 position 0.049" (1.25mm) |  |  |  | Fitted
4 | CN4 | 1 |  | 53398-0571 |  | Wire-To-Board Connector, Vertical, PicoBlade 53398 Series, Surface Mount, Header, 5, 1.25 mm |  |  |  | Fitted
5 | CN3 | 1 |  | B2B-XH-A-M(LF)(SN) |  | CONN HEADER TOP 2POS 2.5MM GRN |  |  |  | Fitted

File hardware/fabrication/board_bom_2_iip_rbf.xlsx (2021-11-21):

 |  |  | Bill of Materials
 |  |  | Source Data From: | 2_iip_rbf.PrjPCB
 |  |  | Project: | 2_iip_rbf.PrjPCB
 |  |  | Variant: | None
 |  |  | Project Code: | IIPN2
 |  |  | Report Date: | 6/28/2021 | 10:27:26 PM
 |  |  | Print Date: | 2021-06-28 | 22:27:30
# | Designator | Quantity | #Column Name Error:Manufacturer | Manufacturer Part Number | #Column Name Error:Partnumber | Description | #Column Name Error:Package | #Column Name Error:Footprint | #Column Name Error:Mount | Fitted
1 | CN3, CN7 | 2 |  | 53398-0671 |  | 1.25mm Pitch PicoBlade™ Header, Surface Mount, Vertical, 6 Circuits |  |  |  | Fitted
2 | CN2, CN6 | 2 |  | M20-9980745 |  | Headers & Wire Housings 07+07 DIL VERTICAL PIN HEADER GOLD HT |  |  |  | Fitted
3 | CN5 | 1 |  | 53398-0471 |  | Connector Header Surface Mount 4 position 0.049" (1.25mm) |  |  |  | Fitted
4 | CN4 | 1 |  | 53398-0571 |  | Wire-To-Board Connector, Vertical, PicoBlade 53398 Series, Surface Mount, Header, 5, 1.25 mm |  |  |  | Fitted
5 | CN1 | 1 |  | M20-9990245 |  | M20 HDR, PIN, SIL, VERT, 2W |  |  |  | Fitted

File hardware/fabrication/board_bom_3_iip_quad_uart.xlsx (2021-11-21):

 |  |  | Bill of Materials
 |  |  | Source Data From: | 3_iip_quad_uart.PrjPCB
 |  |  | Project: | 3_iip_quad_uart.PrjPCB
 |  |  | Variant: | None
 |  |  | Project Code: | IIPN3
 |  |  | Report Date: | 6/28/2021 | 10:34:26 PM
 |  |  | Print Date: | 2021-06-28 | 22:34:32
# | Designator | Quantity | #Column Name Error:Manufacturer | Manufacturer Part Number | #Column Name Error:Partnumber | Description | #Column Name Error:Package | #Column Name Error:Footprint | #Column Name Error:Mount | Fitted
1 | C1, C3, C4, C7, C9, C11, C13, C17, C18, C19, C20, C21, C22, C23 | 14 |  | C1608X7R1H104K080AA |  | TDK - C1608X7R1H104K080AA - SMD Multilayer Ceramic Capacitor, 0.1 µF, 50 V, 0603 [1608 Metric], ± 10%, X7R, C Series |  |  |  | Fitted
2 | C2, C5, C6, C10, C12 | 5 |  | C2012X7R1E475K125AB |  | Ceramic Capacitor SMD Multilayer, 0805 [2012 Metric], 4.7 uF, 25 V, 10%, X7R, C Series |  |  |  | Fitted
3 | FB1, FB2, FB3 | 3 |  | 742792608 |  | WURTH ELEKTRONIK 742792608 FERRITE BEAD, 0.1 OHM, 0.5A, 0603 |  |  |  | Fitted
4 | R5, R6, R7 | 3 |  | CRCW080510K0FKEA |  | RES 10.0K OHM 1/8W 1% 0805 SMD |  |  |  | Fitted
5 | C8, C14 | 2 |  | 08055C103KAT4A |  | AVX - 08055C103KAT4A - SMD Multilayer Ceramic Capacitor, 10000 pF, 50 V, 0805 [2012 Metric], &#177; 10%, X7R |  |  |  | Fitted
6 | CN1, CN3 | 2 |  | 53398-0571 |  | Wire-To-Board Connector, Vertical, PicoBlade 53398 Series, Surface Mount, Header, 5, 1.25 mm |  |  |  | Fitted
7 | C15, C16 | 2 |  | CL10C120JB8NNNC |  | Cap Ceramic 12pF 50VDC C0G 5% SMD 0603 Paper T/R |  |  |  | Fitted
8 | R1, R2 | 2 |  | RC0603FR-0710RL |  | YAGEO (PHYCOMP) - RC0603FR-0710RL - RES, THICK FILM, 10R, 1%, 0.1W, 0603 |  |  |  | Fitted
9 | CN2 | 1 |  | 651005136421 |  | WURTH ELEKTRONIK - 651005136421 - Conector USB, Mini USB Tipo B, USB 2.0, Receptáculo, 5 Vías, Montaje de Agujero Pasante, Vertical |  |  |  | Fitted
10 | XTAL1 | 1 |  | AA-12.000MAGE-T |  | Crystals 12.000MHz 30ppm 12pF -40C to 85C |  |  |  | Fitted
11 | R4 | 1 |  | CRCW08050000Z0EA |  | VISHAY - CRCW08050000Z0EA - SMD Chip Resistor, Jumper, 0805 [2012 Metric], 0 ohm, CRCW e3 Series, 150 V, Thick Film, 125 mW |  |  |  | Fitted
12 | U1 | 1 |  | FT4232HL-REEL |  | FTDI - FT4232HL-REEL - USB-UART/MPSSE, 4232, QUAD, 64LQFP |  |  |  | Fitted
13 | R3 | 1 |  | RMCF0805FT12K0 |  | Resistor, SMT, 0805, 12K Ohm, +/-1%, +/-100ppm, Thk Film, T/R Marked |  |  |  | Fitted
14 | U2 | 1 |  | TPS79333DBVR |  | TEXAS INSTRUMENTS - TPS79333DBVR - IC, V REG, LINEAR, 0.2A, SOT-23-5 |  |  |  | Fitted

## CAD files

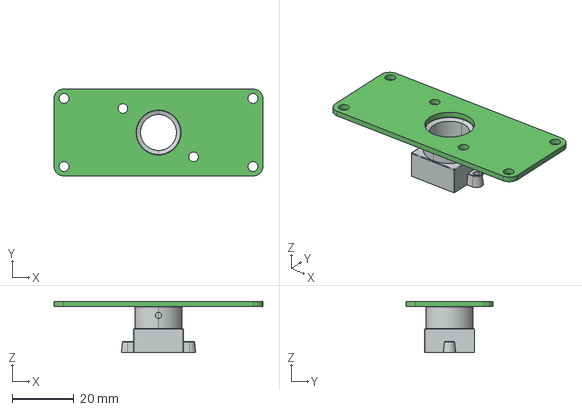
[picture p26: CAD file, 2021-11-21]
hardware/outputs/board_3dmodels/step_3dmodel_iip_camera.step
67.5 x 28.0 x 16.5 mm

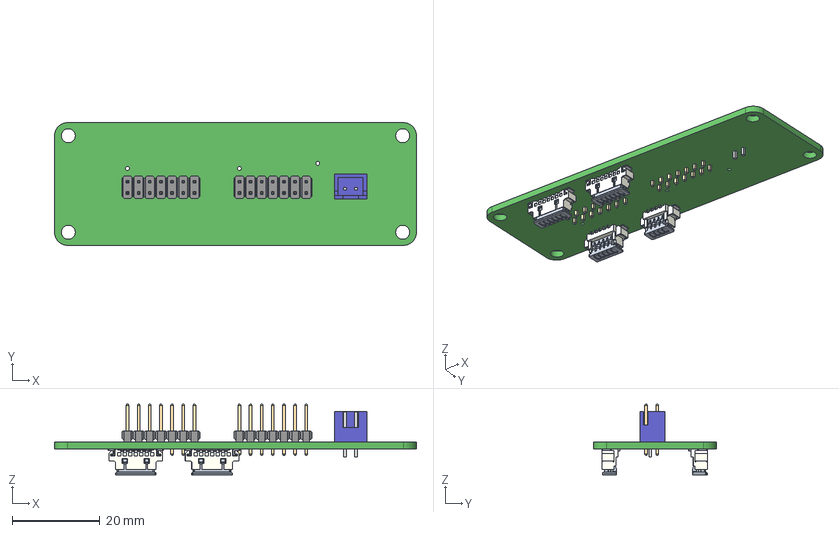
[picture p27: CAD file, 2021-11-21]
hardware/outputs/board_3dmodels/step_3dmodel_iip_charge.step
82.5 x 28.0 x 16.1 mm
Board1_IIP_Charge
User_Library-molex_53398_white_(3)
510210500_5posHousingPicoblade
M20-998-MOULD x 2
M20-998-PIN x 28
B2B-XH-A
User_Library-molex_53398_white_(2)
510210400_4posHousingPicoblade
User_Library-molex_53398_white_(4) x 2
510210600_6posHousingPicoblade x 2

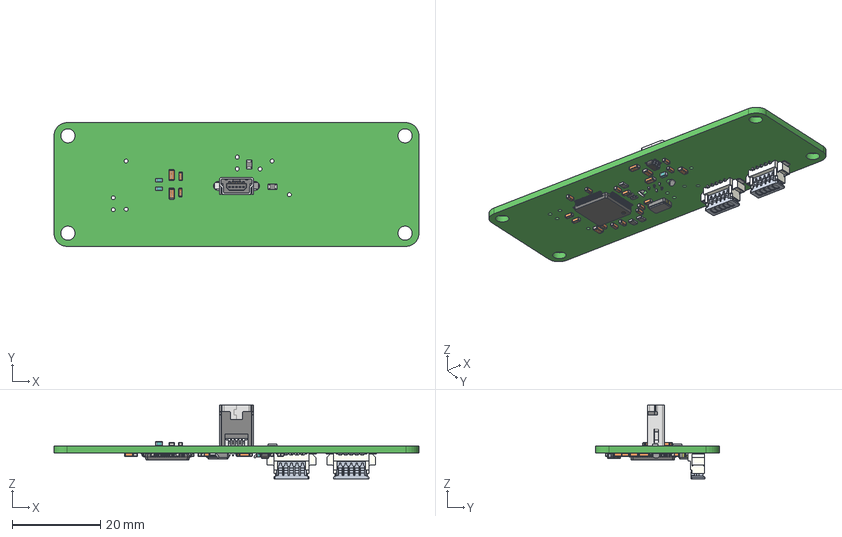
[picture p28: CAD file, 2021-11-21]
hardware/outputs/board_3dmodels/step_3dmodel_iip_quad_uart.step
82.5 x 28.0 x 16.7 mm
Board3_iip_quad_uart
User_Library-445-CRYTAL-SMD
SOT23-5
User_Library-LQFP64_Grid_0.5_LQFP64_Koerper_2
User_Library-LQFP64_Grid_0.5_LQFP_PIN_2 x 64
Flat_Chip_Resistor_0805(2012M) x 5
Flat_Chip_Resistor_0603(1608M) x 2
User_Library-Chip_Inductor_(1) x 3
User_Library-molex_53398_white_(3) x 2
510210500_5posHousingPicoblade x 2
Shielding
Insulator
Pin_1 x 3
Pin_2 x 2
C0603 x 16
C0805 x 7

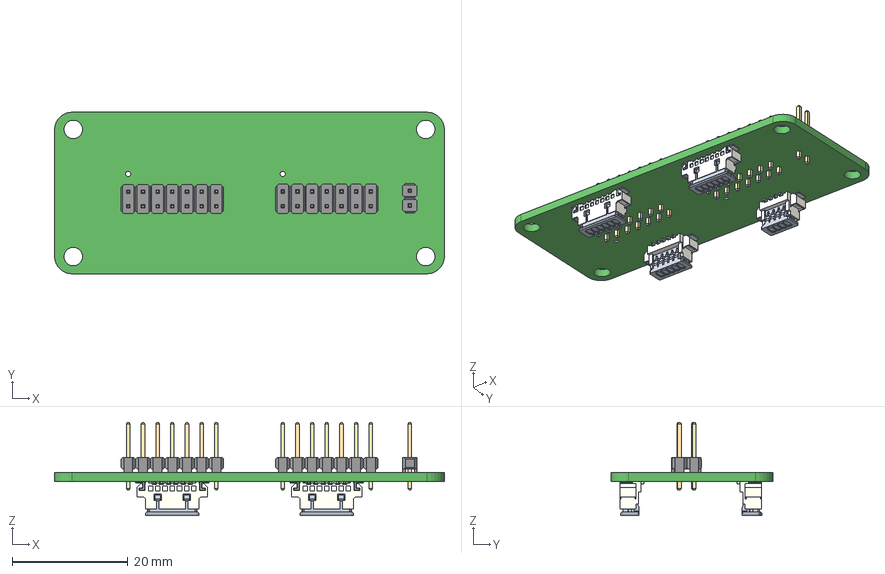
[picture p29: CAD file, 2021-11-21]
hardware/outputs/board_3dmodels/step_3dmodel_iip_rbf.step
67.5 x 28.0 x 16.1 mm
Board2_iip_rbf
User_Library-molex_53398_white_(2)
510210400_4posHousingPicoblade
M20-999-MOULD
M20-999-PIN x 2
User_Library-molex_53398_white_(4) x 2
510210600_6posHousingPicoblade x 2
M20-998-MOULD x 2
M20-998-PIN x 28
User_Library-molex_53398_white_(3)
510210500_5posHousingPicoblade

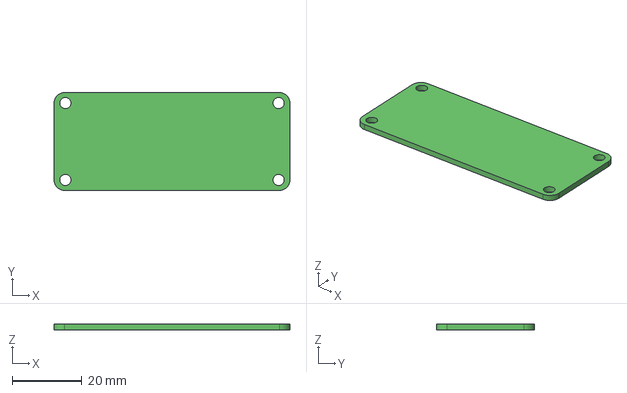
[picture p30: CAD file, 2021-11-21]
hardware/outputs/board_3dmodels/step_3dmodel_iip_closure.step
67.5 x 28.0 x 1.59 mm

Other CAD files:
hardware/outputs/board_3dmodels/parasolid_3dmodel_iip_charge.x_t
hardware/outputs/board_3dmodels/parasolid_3dmodel_iip_quad_uart.x_t
hardware/outputs/board_3dmodels/parasolid_3dmodel_iip_rbf.x_t
semi_usb_interface/Output files of all boards/PARASOLID files/1_Interface_Charge_RBF.x_t
semi_usb_interface/Output files of all boards/PARASOLID files/2_Interface_JTAG.x_t

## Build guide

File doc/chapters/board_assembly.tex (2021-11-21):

%
% board_assembly.tex
%
% Copyright © 2021 by Universidade Federal de Santa Catarina.
%
% Documentation of Interstage Interface Panels
%
% This work is licensed under the Creative Commons Attribution-ShareAlike 4.0
% International License. To view a copy of this license,
% visit http://creativecommons.org/licenses/by-sa/4.0/.
%

%
% \brief Assembly instructions chapter.
%
% \author Yan Castro de Azeredo <yan.azeredo@spacelab.ufsc.br>
%
% \institution Universidade Federal de Santa Catarina (UFSC)
%
% \version 2.0.0
%
% \date 05/07/21 (DD/MM/YY)
%
% \note Credits to Gabriel Mariano Marcelino <gabriel.marcelino@spacelab.ufsc.br> for the creation of the SpaceLab Template
%

\chapter{Board Assembly} \label{ch:board-assembly}

IIP has the Bill of Material (BOM) for each board avalaible at its GitHub repository in excel spreeadsheets format. Also the PCBs can be assembled by a Pick-and-place machine using the .txt file found on the hardware/fabrication folder if desired, fiducials are placed on each board to make this possible. All components are to be fitted on the IIP boards, the only exception is the one described below. The draftsman PDF documents of each board shows all the components positioning, they can be found here \cite{iip-draftsman}.

\section{DNP component}

There is only one "do not place" (DNP) component present in the Nº3 board, it is the labeled R4 pad with 0805 size (2012 metric) available for soldering the mini USB type B chassi to GND for Electromagnetic compatibility (EMC), see \ref{fig:iip-usb-port}. This can be done soldering a zero-ohm resistor for a DC path or capacitor for a high-frequency path between shield and signal ground, see section 2.2.2 of the document \cite{ftdi-usb-hardware-guidelines}.

\section{Integration} \label{sec:integration}

IIP board Nº1 is to be mouted vertically inside the 2U/3U strucuture on the -X referenced plane.
IIP board Nº3 is to be mouted in the same plane of reference but in the other side, that is the +X plane.
IIP board Nº2 is to be mouted on the -Y plane, while the IIP board Nº4 on the +Y plane.
The integration order of the interface panels follows their numeration, this means the first PCB to be integrated is Nº1, then Nº2, Nº3 and at last Nº4.
The internal PicoBlade connections to the modules must be done before proceding to mount the other panels.

The last cables to be connected are between Nº3 (figure \ref{fig:iip-n3-picoblades}) and Nº1 and Nº2 (figures \ref{fig:iip-n1-uart-picoblade} and \ref{fig:iip-n2-uart-picoblade}) for the labeled "UART" PicoBlades. The only interface of IIP that can be acessed when the 2U satellite is already integrated to the P-POD is the Nº2 board which is located the RBF pin and JTAGs 3 and 4.

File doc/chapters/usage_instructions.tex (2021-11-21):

%
% usage_instructions.tex
%
% Copyright © 2021 by Universidade Federal de Santa Catarina.
%
% Documentation of Interstage Interface Panels
%
% This work is licensed under the Creative Commons Attribution-ShareAlike 4.0
% International License. To view a copy of this license,
% visit http://creativecommons.org/licenses/by-sa/4.0/.
%

%
% \brief Usage instructions chapter.
%
% \author Yan Castro de Azeredo <yan.azeredo@spacelab.ufsc.br>
%
% \institution Universidade Federal de Santa Catarina (UFSC)
%
% \version 2.0.0
%
% \date 06/07/21 (DD/MM/YY)
%
% \note Credits to Gabriel Mariano Marcelino <gabriel.marcelino@spacelab.ufsc.br> for the creation of the SpaceLab Template
%

\chapter{Usage Instructions} \label{ch:usage_instructions}

IIP interfaces can be used depending on the project if it's followed the hardware features and constraints.

\section{Charging batteries}

To charge the batteries it will be needed a cable compatible with the JST XH header. The compatible housing is a XHP-2 receptacle, the jumper lead socket to socket to be used can be ASXHSXH22K305, or any other with AWG \#30 to \#22. The only constraint is that the current cannot excel 2000mA, because the PicoBlades connectors used to interconnect the JST header to the modules only support 1000mA per pin. For safe usage it is recommended to use the header with a 1500mA maximum charge current.

\section{Programming and Debugging Modules Though JTAG}

Following the pinout of the pin headers showed at \ref{tab:jtag-headers-pinout} the JTAG interface can be used according to any debugger and programmer tool and cable assembly with dual row 14 pin 2.54mm pitch. If more than one pin header is to be used simultaneously in the same panel, the length of the cable assemblies housing must be considered to avoid mechancial incopability. For IIP it was tested on a EDA tool using a 61201423021 14 Position Rectangular Receptacle Connector from Würth Elektronik, garanting the use of the default cable of the MSP-FET in this situation.

\section{Debugging though USB}

Connecting a type A to mini type B USB cable to a PC and the USB port present on IIP Nº3, the four USB to UART channels should be ready to be used. Note that the computer will recognize the port as four different devices. The IIP Nº3 doesn't have an EEPROM, so it will be already configured to operate as default serial ports. The FT4232H will have the built-in default VID (0403) and PID (6011).

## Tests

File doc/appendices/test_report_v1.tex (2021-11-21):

%
% test_report_v1.tex
%
% Copyright (C) 2021 by SpaceLab.
%
% Documentation of Interstage Interface Panels
%
% This work is licensed under the Creative Commons Attribution-ShareAlike 4.0
% International License. To view a copy of this license,
% visit http://creativecommons.org/licenses/by-sa/4.0/.
%

%
% \brief Test report of the v1.0 hardware.
%
% \author Yan Castro de Azeredo <yan.azeredo@spacelab.ufsc.br>
%
% \institution Universidade Federal de Santa Catarina (UFSC)
%
% \version 0.2.0
%
% \date 2021/07/12
%

\chapter{Test Report of v1.0 Version} \label{anx:test-report-v1}

This appendix is a test report of the first manufactured and assembled PCB (version v1.0).
Only IIP Nº1, Nº2 and Nº3 boards were acquired.

\begin{itemize}
    \item \textbf{PCB manufacturer}: PCBWay (China)
    \item \textbf{PCB assembly}: PCBWay (China)
    \item \textbf{PCB arrival date}: 2021/04/14
    \item \textbf{Execution date}: 2021/04/DD to \textcolor{red}{TBD}
    \item \textbf{Tester}: \textcolor{red}{TBD}
\end{itemize}

\begin{figure}[!ht]
    \begin{center}
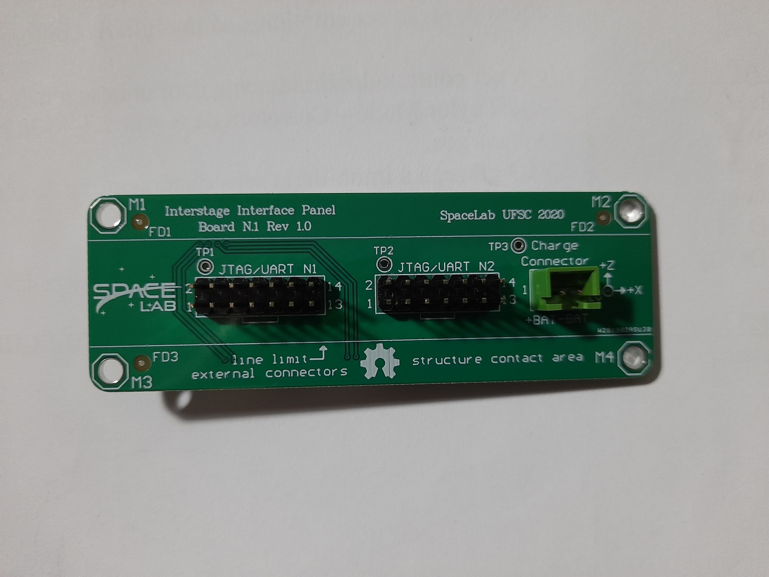
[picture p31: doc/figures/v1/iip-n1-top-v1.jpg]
        
        \caption{Interface Intertage Panel Nº1 top view.}
        \label{fig:iip-n1-v1-top}
    \end{center}
\end{figure}

\begin{figure}[!ht]
    \begin{center}
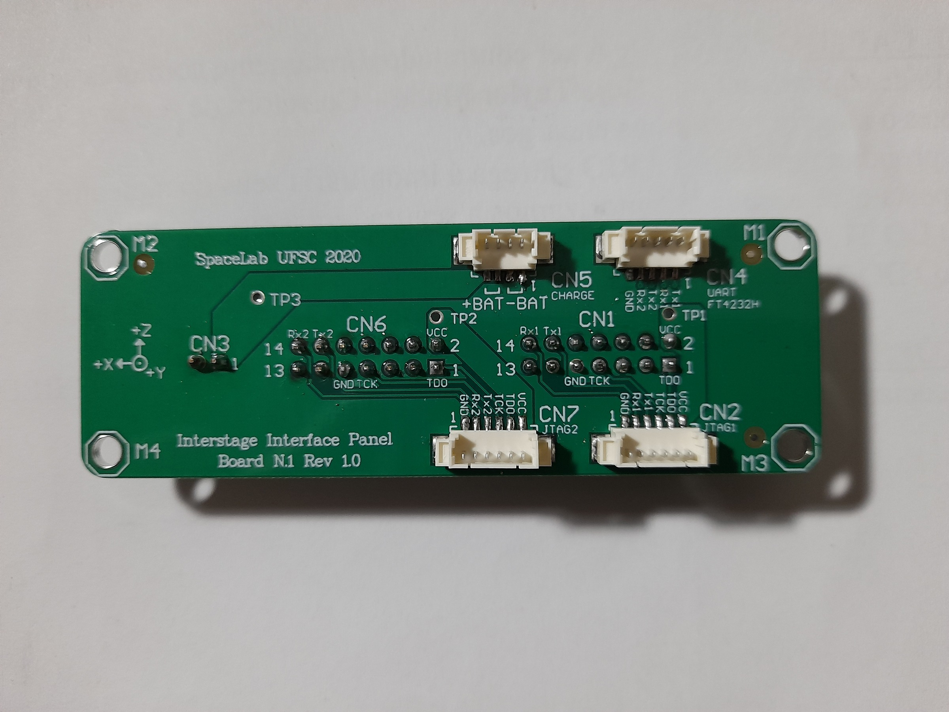
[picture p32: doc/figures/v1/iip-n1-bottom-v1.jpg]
        
        \caption{Interface Intertage Panel Nº1 bottom view.}
        \label{fig:iip-n1-v1-bottom}
    \end{center}
\end{figure}

\begin{figure}[!ht]
    \begin{center}
        
        \caption{Interface Intertage Panel Nº2 top view.}
        \label{fig:iip-n2-v1-top}
    \end{center}
\end{figure}

\begin{figure}[!ht]
    \begin{center}
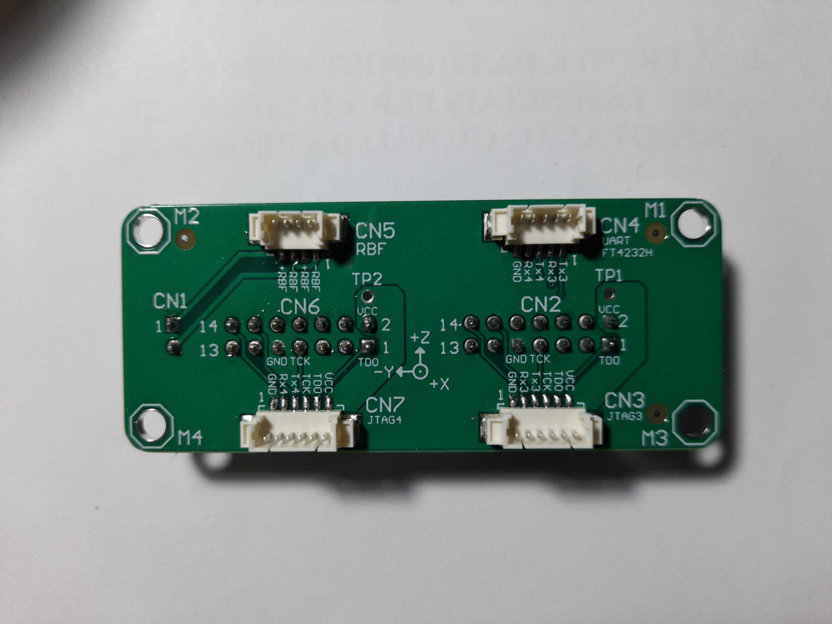
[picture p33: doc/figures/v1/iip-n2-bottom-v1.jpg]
        
        \caption{Interface Intertage Panel Nº2 bottom view.}
        \label{fig:iip-n2-v1-bottom}
    \end{center}
\end{figure}

\begin{figure}[!ht]
    \begin{center}
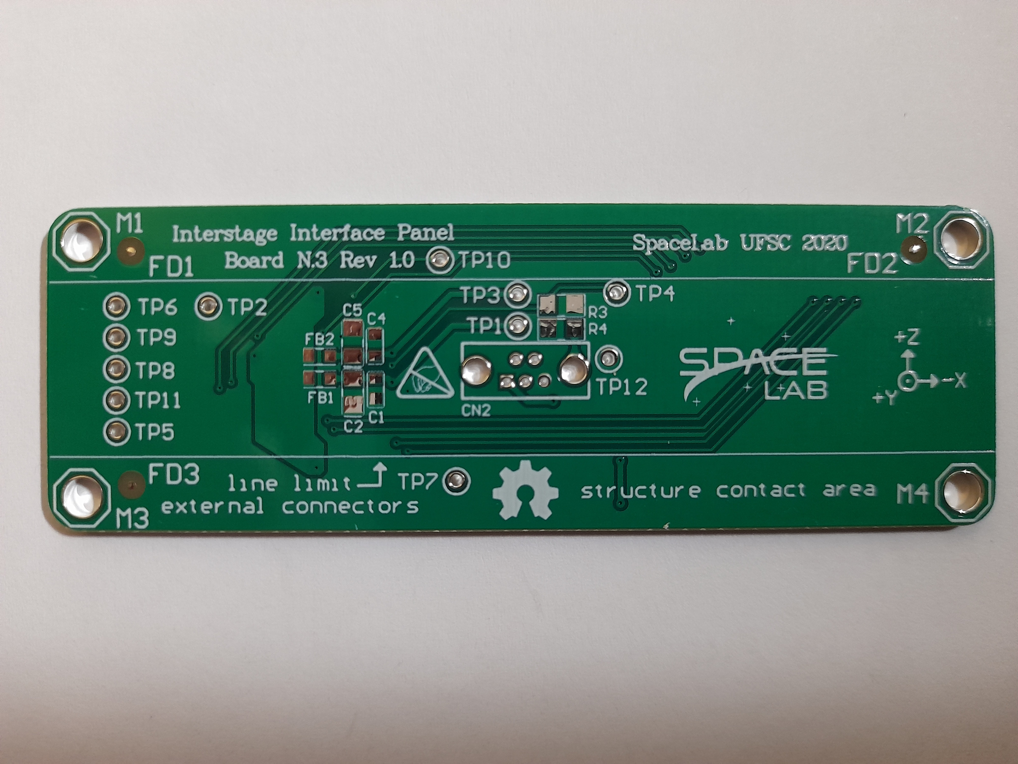
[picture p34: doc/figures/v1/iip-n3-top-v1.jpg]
        
        \caption{Interface Intertage Panel Nº3 top view.}
        \label{fig:iip-n3-v1-top}
    \end{center}
\end{figure}

\begin{figure}[!ht]
    \begin{center}
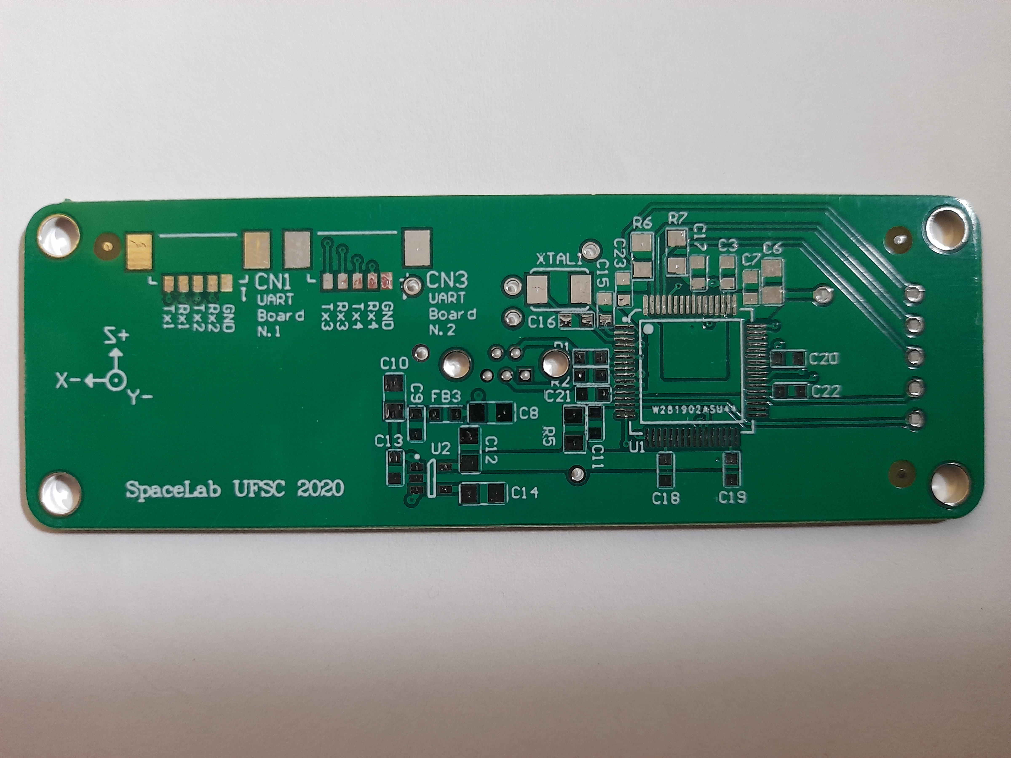
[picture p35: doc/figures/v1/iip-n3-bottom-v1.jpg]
        
        \caption{Interface Intertage Panel Nº3 bottom view.}
        \label{fig:iip-n3-v1-bottom}
    \end{center}
\end{figure}

\section{Visual Inspection}

\begin{itemize}
    \item \textbf{Test description/Objective}: Inspection of the board, visually and with a multimeter, searching for fabrication and assembly failures.
    \item \textbf{Material}:
        \begin{itemize}
            \item Multimeter UNI-T DT830B
        \end{itemize}
    \item \textbf{Results}: \textcolor{red}{TBD}.
    \item \textbf{Conclusion}: \textcolor{red}{TBD}.
\end{itemize}

\section{Mechanical validation}

\begin{itemize}
    \item \textbf{Test description/Objective}: Verify mounting hole sizes, distances, connector heights and silkscreen sinalization. A full assembly of the nanosatellite can be emulated to better test cable managment with connectors positioning.
    \item \textbf{Material}:
        \begin{itemize}
            \item CubeSat 2U or 3U structure 
        \end{itemize}
    \item \textbf{Results}: \textcolor{red}{TBD}.
    \item \textbf{Conclusion}: \textcolor{red}{TBD}.
\end{itemize}

\section{Conclusion}

\textcolor{red}{TBD}

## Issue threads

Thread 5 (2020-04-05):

Verify space limit for external and internal connectors

YanAzer, 2020-04-05:
External connectors can cross the P-POD limit and internal connectors can get in the way of cables or inter-board connections like the PC104.

YanAzer, 2020-04-10:
**3.2.3** "No components on the green and yellow shaded sides shall exceed 6.5mm normal to the surface" on page 10.
**3.2.8** "The ends of the railson the +/-Z face shall have a minimum surface area of 6.5mm x 6.5mm contact area for neighboring CubeSat rails (as per Figure 6)." on page 10.
**3.3.7.3** "The RBF pin shall protrude no more than 6.5 mm from the rails when it is fully inserted into the satellite." on page 13.
Source: https://static1.squarespace.com/static/5418c831e4b0fa4ecac1bacd/t/56e9b62337013b6c063a655a/1458157095454/cds_rev13_final2.pdf

YanAzer, 2020-04-15:
It is possible to use a connector with maximum height of 10mm, possibly even with 12mm. Initial integration test done with 8mm pins mounted in the interface board inside the 2U Cubesat Structure is portraited in the images below.
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

Closed 2020-04-15.

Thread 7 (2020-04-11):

Define component placement for semi USB variant boards

YanAzer, 2020-04-11:
The components placement needs to take into consideration the maximum 6.5mm external distance beyong the default 100mm of the X and Y plane. Depending on the mouting of the PCB on front or inside the 2U CubeSat structure, the height limit of external connectors can vary (pcb thickness + structure thickness).
The semi USB variant uses individual connectors for interfacing JTAG into each module.

YanAzer, 2020-04-15:
Preliminary plan (without doing any PCB layout yet)

**Pcb board 1º:** Quad UART using one USB port through FT4232H IC, four 6 pin picoblade connectors (UART + JTAG connections). This board will be integrated in the -Y side of the 2U CubeSat structure.
**Pcb board 2º:** JTAG header 5 line and double row pins (5x2) compatible with standard Texas Instruments CC Debugger cable connector, 4 pin power header for charging batteries. This board will be integrated in the -X side of the 2U CubeSat structure.
**Pcb board 3º:** Empty of components, possible only silk screen labels. This board will be integrated in the +Y side of the 2U CubeSat structure.
**Pcb board 4º:** Empty of components, possible only silk screen labels. This board will be integrated in the +X side of the 2U CubeSat structure.
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

YanAzer, 2020-05-04:
Updated plan (with initial PCB layout observations)

**Pcb board 1º:** Quad UART using one USB port through FT4232H IC and one 9x1 pin Picoblade for bringing UART signals to **Pcb board 2º**. This board will be integrated in the -Y side of the 2U CubeSat structure.
**Pcb board 2º:** Four 7x2 pin headers compatible with standard MSP-FET cable connector for mainly JTAG and optional UART communication, one 9x1 pin Picoblade for bringing UART signals from **Pcb board 1º** and four 4x1 pin PicoBlades for connecting JTAG and UART with the sattelite's modules. This board will be integrated in the +X side of the 2U CubeSat structure.
**Pcb board 3º:** One 2 pin header for Remove Before Flight (RBF) and one 4 pin connector for charging batteries. This board will be integrated in the -X side of the 2U CubeSat structure.
**Pcb board 4º:** Empty of components, possible only silk screen labels. This board will be integrated in the +Y side of the 2U CubeSat structure.

YanAzer, 2020-06-04:
Updated plan (considering ongoing pcb layout)

Board Nº1: Two 7x2 pin headers compatible with standard MSP-FET cable connector for mainly JTAG and optional UART debbug, one 5x1 pin Picoblade for interfacing UART debbug signals from board Nº3, two 4x1 pin PicoBlades for interfacing SBW with the sattelite's modules, one 2x1 pin JST header for charging batteries and one 2x1 pin header for remove before flight (RBF) switch.
This board will be integrated in the -X side of the 2U CubeSat structure.

Board Nº2: Two 7x2 pin headers compatible with standard MSP-FET cable connector for mainly JTAG and optional UART debugg, one 5x1 pin Picoblade for interfacing UART debugg signals from boards Nº3.
This board will be integrated in the -Y side of the 2U CubeSat structure.

Board Nº3: Quad UART channel FT4232H IC interfacing though a USB mini B port and two 5x1 pin Picoblade for interfacing UART debbug signals from boards Nº1 and Nº2.
This board will be integrated in the +Y side of the 2U CubeSat structure.

Board Nº4: Empty of components, possible only silk screen labels. This board will be integrated in the +X side of the 2U CubeSat structure.

Closed 2020-06-16.

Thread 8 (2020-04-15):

Define component placement for full USB variant boards

YanAzer, 2020-04-15:
Preliminary planning (without doing any PCB layout yet)

**Pcb board 1#:** Quad UART using one USB port through FT4232H, four 6 pin picoblade connectors (UART + JTAG connections). This board will be integrated in the -Y side of the 2U CubeSat structure.

**Pcb board 2#:** Double JTAG using one USB port through FT4232H and two picoblade 4 pin for interfacing JTAG and UART signals with pcb board 1º. This board will be integrated in the -X side of the 2U CubeSat structure.

**Pcb board 3#:** Double JTAG using one USB port through FT4232H and two picoblade 4 pin for interfacing JTAG and UART signals with pcb board 1º. This board will be integrated in the +Y side of the 2U CubeSat structure.

**Pcb board 4#:** 4 pin power header for charging batteries. This board will be integrated in the +X side of the 2U CubeSat structure.

Note: pcb board 3º and 4º will have the same circuit.

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

YanAzer, 2021-01-27:
This issue will not be worked on (maybe ever but who knows).

Closed 2021-01-27.

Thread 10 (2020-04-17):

Create the "2_IIP_RBF" schematic sheet

YanAzer, 2020-04-17:
This schematic will have four JTAG headers 5 line and double row pins (5x2) compatible with standard Texas Instruments CC Debugger cable connector, four picoblades 4 pin for interfacing JTAG and UART signals with the quad UART pcb and one 4 pin power header for charging batteries.

YanAzer, 2020-04-17:
Initial drawing was already done and uploaded through https://github.com/spacelab-ufsc/interface-board/commit/f9ea50bbeab169880fb09b68b5abd61b1601cb00

Closed 2020-07-13.

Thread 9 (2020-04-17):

Create the "3_Interface_QuadUART" schematic sheet

YanAzer, 2020-04-17:
This schematic will have a FT4232H with four UART channels through a mini B USB port, four 6 pin picoblade connectors for UART and JTAG connections.

YanAzer, 2020-04-17:
Initial drawing was already done and uploaded through https://github.com/spacelab-ufsc/interface-board/commit/f9ea50bbeab169880fb09b68b5abd61b1601cb00

YanAzer, 2020-05-07:
Renamed schematic sheet with the commit 86119f8b1e61b6e363c109160a3f74f0e39f876c, consequently this changes the title of this issue.

Closed 2020-06-28.

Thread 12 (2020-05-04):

Create the "1_IIP_Charge" schematic sheet

YanAzer, 2020-05-04:

YanAzer, 2020-05-07:
Renamed schematic sheet with the commit https://github.com/spacelab-ufsc/interface-board/commit/aca9b67ee3b91a1f3ad1b9ff83266b589bba1227, consequently changes the title of this issue.

Closed 2020-07-02.

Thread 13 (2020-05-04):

Create the pcb layout for the 1_IIP_Charge schematic sheet

YanAzer, 2020-05-04:

YanAzer, 2020-05-07:
Renamed pcb document with the commit aca9b67, consequently this changes the title of this issue.

Closed 2020-07-02.

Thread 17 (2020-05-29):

Generate 3D models of N1 and N2 boards for second mechanical evaluation

YanAzer, 2020-05-29:
N1 board: 1_Interface_Charge_RBF.PcbDoc
N2 board: 2_Interface_JTAG.PcbDoc

Changes made from first mechancial evaluation:
1. Removed 1mm of heigh and shorted the distance from mechanical holes by 1mm on both boards;
2. Removed 7,5 mm from both sides on N2 board;

Closed 2020-06-16.

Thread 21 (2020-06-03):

Define ESD protection circuit for USB 2.0 header in board N3

YanAzer, 2020-06-03:
N3 board is refering to 3_Interface_QuadUART PCB.

Some sources found for guidance:
https://www.ftdichip.com/Support/Documents/AppNotes/AN_146_USB_Hardware_Design_Guidelines_for_FTDI_ICs.pdf
[USB 2.0 Board Design and Layout Guidelines.pdf](https://github.com/spacelab-ufsc/interface-board/files/4726653/USB.2.0.Board.Design.and.Layout.Guidelines.pdf)

YanAzer, 2020-06-11:
Options found for ESD protection for data lines (D+ and D-):
1) https://www.digikey.com/product-detail/en/texas-instruments/ESD122DMYR/296-47120-1-ND/7603879;
2) https://www.digikey.com/product-detail/en/texas-instruments/TPD2E1B06DRLR/296-37298-1-ND/4746300;

Note: TLP failure is not the same as absolute maximum voltage values found on FT4232H datasheet. Absolute maximum voltage is a DC voltage while TLP is a 100ns transient (source: https://training.ti.com/esd-essentials-how-select-esd-protection?context=1136983-1139548-1135655). The exact value of this parameter is not always easy to find, so the choice of the protection will be based in general guidelines and hardware choices done in evaluation modules, such as FT4232H Mini Module.

YanAzer, 2020-06-16:
Option found for ESD protection for VBUS line:
https://www.digikey.com/product-detail/en/texas-instruments/TPD1E10B06DPYR/296-30406-1-ND/3283560
Waiting to found similar component with bigger package size than 0402 (1006 Metric).

YanAzer, 2020-06-23:
ESD protection for the N3 was discarded to simplify project design.

Closed 2020-06-23.

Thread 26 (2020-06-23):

Move RBF pin header from N1 to N2 board

YanAzer, 2020-06-23:
Currently the N1 board (1_Interface_Charge_RBF to be mounted in the -Y plane) has a 2 pin header for RBF switch, for the correct integration in the P-POD it must be moved to the N2 board (2_Interface_JTAG to be mounted in the -X plane).

Source: https://static1.squarespace.com/static/5418c831e4b0fa4ecac1bacd/t/56e9b62337013b6c063a655a/1458157095454/cds_rev13_final2.pdf
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

mgm8, 2020-06-28:
@YanAzer this is not a big issue, as can be seen [here](https://youtu.be/ECmqEms8u_Q?t=302), sometimes the RBF is removed before installing the satellite in the P-POD.

YanAzer, 2020-06-29:
@mgm8 i already did the changes along the week, didn't commited because i didn't want to mix with the history of the N3 board on the recently pull request. Doing this change actually helped since i needed to move the picoblade headers (#27) and somewhat distributed the weight on both PCBs.

Closed 2020-08-08.

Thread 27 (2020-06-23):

Fix picoblade header positioning in N1 and N2 boards

YanAzer, 2020-06-23:
Example is portaited below, the X marked picoblade header on the image must be removed according to #26. Only the FT4232H picoblade (right side of the pic) must be moved in N2 board.
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

Closed 2020-08-08.

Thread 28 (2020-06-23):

Fix fiducials small bottom solder

YanAzer, 2020-06-23:
The fiducials are placed in all the boards of the project board for convenience.

Closed 2020-08-08.

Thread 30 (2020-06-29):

Generate first output files for IIP semi USB

YanAzer, 2020-06-29:
The files to be generated for each three boards (N1, N2 and N3) are:

- .OutJob file configuration
- BOM.xls
- SCH.pdf
- GERBERS.zip
- NC Drill files.zip
- Pick and Place files.zip
- ODB++.zip

Closed 2020-08-08.

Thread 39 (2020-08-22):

Hardware: Update the boards to the new PCB standard

andrempmattos, 2020-08-22:

YanAzer, 2021-01-27:
The repository didn't follow perfectly the (PCB standard rules)[] since it was a hardware project of 3 boards, but many changes were done to improve the overall source files names, directory organization and output. The changes were done with many commits, just to name a few 236cfc2598377997e421c57118ccf303d5609164, 478ef096d5f2498a74f3d4c07593be2dd4aa01b6, 6cdae57a20f86435ae860cb2187526eccee5501d, 7e1c9b9f878a1c758af2270bdad553cf3c6d72dc (the last).

Closed 2021-01-27.

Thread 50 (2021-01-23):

Doc: Add a image presenting the placement/attachment relative to the structure

andrempmattos, 2021-01-23:
Reference image:
https://github.com/andrempmattos/cubesat-solar-panels/blob/main/documentation/figures/15.png
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

Add it in the main readme too.

Note: This issue is non-critical.

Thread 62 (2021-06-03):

Hardware: Make a variant of Nº4 IIP board considering a camera opening

YanAzer, 2021-06-03:

mgm8, 2021-06-03:
@YanAzer as the camera module is a just an idea for now, I think we can keep two variants of the Nº4 IIP board:

* One without any connector or components (a "blank" PCB)
* One with a camera "slot"

YanAzer, 2021-06-03:
Noted @mgm8 just fixing the issue name for now.

Closed 2021-07-12.

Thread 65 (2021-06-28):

Release v2.0

YanAzer, 2021-06-28:
- [x] Update revision history table on schematic
- [x] Update all fabrication outputs
- [x] Update outputs Nº1 board
- [x] Update outputs Nº2 board
- [x] Update outputs Nº3 board
- [x] Update outputs Nº4 board
- [x] #67
- [x] Remove unnecessary ouput files
- [x] Update multi board assembly project file
- [x] Add the fourth interface board to documentation
- [x] Update readmes

Closed 2021-07-12.

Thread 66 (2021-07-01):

Hardware: Fix ODB++ importing error

YanAzer, 2021-07-01:
Currently importing the ODB++ files of the boards are not working, may be caused by a outjob file configurarion. This issue is not so critial since the other fabrication and output files serves the same purpose as the resulting camtastic from ODB++.

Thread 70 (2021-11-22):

hardware: Fix the description of the FB1, 2 and 3 of  IIP Quad UART board

mgm8, 2021-11-22:
The description of FB1, FB2 and FB3 is wrong and do not match the correct part number of this component.

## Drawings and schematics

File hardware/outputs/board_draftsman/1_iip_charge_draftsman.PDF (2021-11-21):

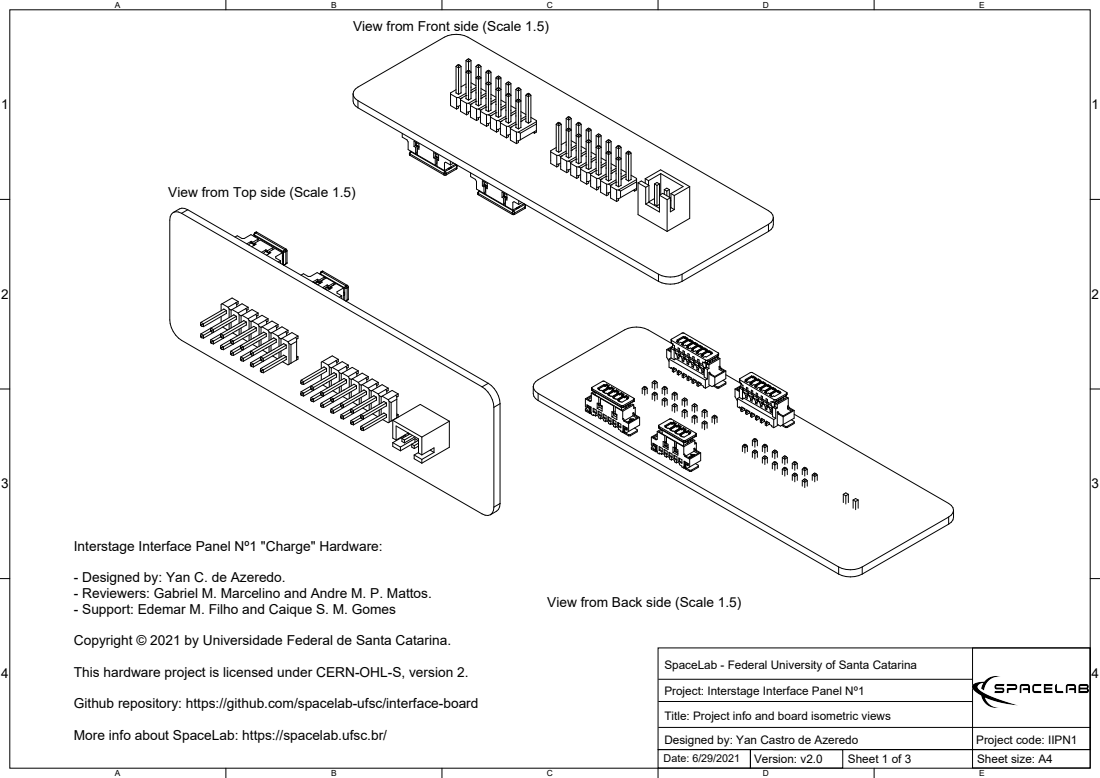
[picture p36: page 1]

View from Front side (Scale 1.5)

View from Top side (Scale 1.5)

Interstage Interface Panel Nº1 "Charge" Hardware:

- Designed by: Yan C. de Azeredo.
- Reviewers: Gabriel M. Marcelino and Andre M. P. Mattos.
- Support: Edemar M. Filho and Caique S. M. Gomes

View from Back side (Scale 1.5)

Copyright © 2021 by Universidade Federal de Santa Catarina.

SpaceLab - Federal University of Santa Catarina

This hardware project is licensed under CERN-OHL-S, version 2.

Project: Interstage Interface Panel Nº1

Github repository: https://github.com/spacelab-ufsc/interface-board

Title: Project info and board isometric views
Designed by: Yan Castro de Azeredo

More info about SpaceLab: https://spacelab.ufsc.br/

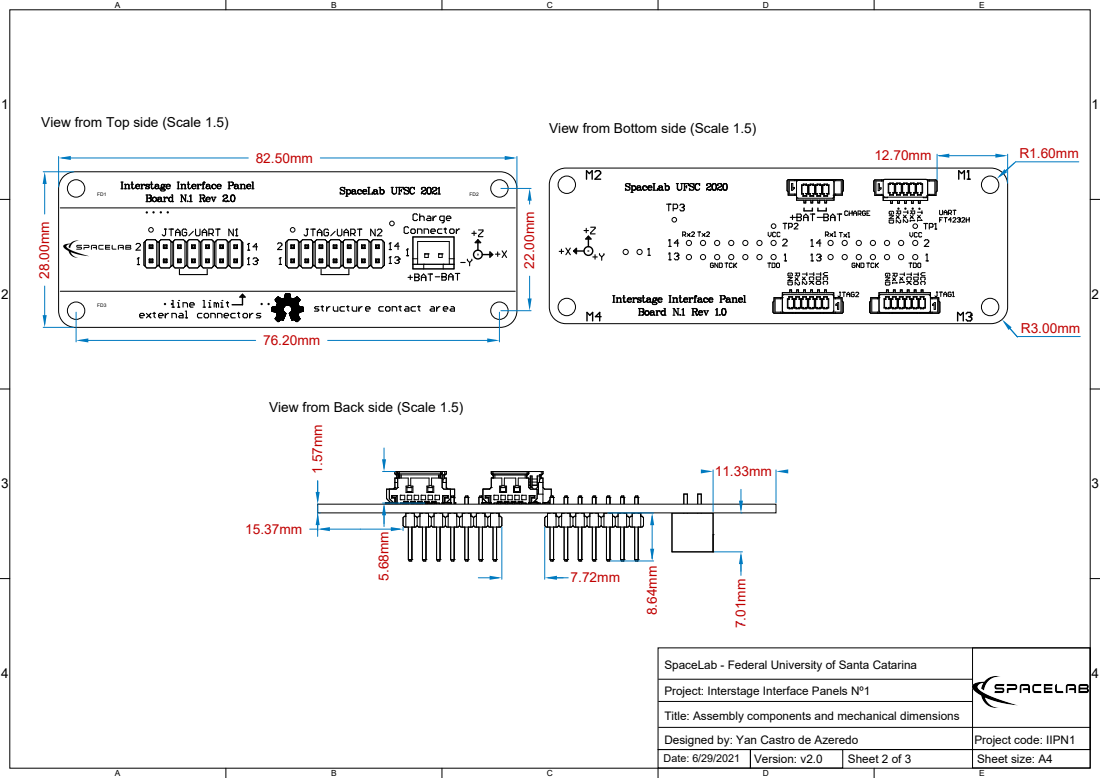
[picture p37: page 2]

View from Top side (Scale 1.5)

View from Bottom side (Scale 1.5)

View from Back side (Scale 1.5)

SpaceLab - Federal University of Santa Catarina

Project: Interstage Interface Panels Nº1

Title: Assembly components and mechanical dimensions

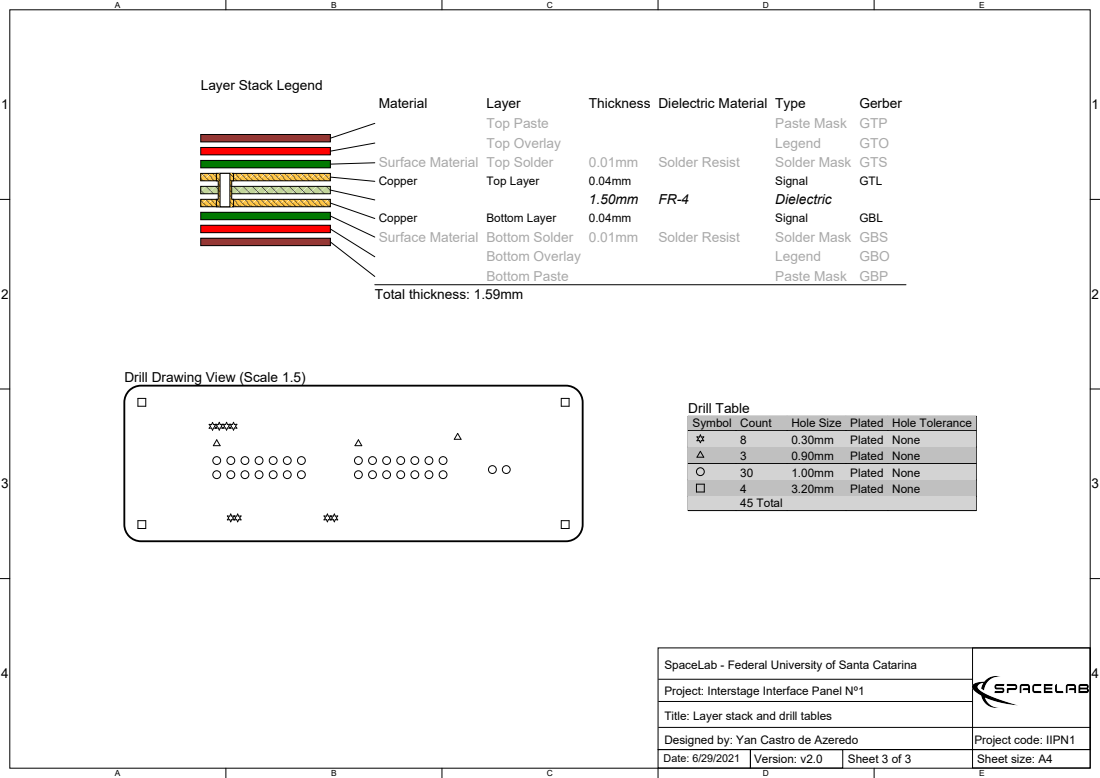
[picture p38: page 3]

Drill Drawing View (Scale 1.5)

Symbol | Count | Hole Size | Plated | Hole Tolerance

8 | 0.30mm | Plated | None
3 | 0.90mm | Plated | None
30 | 1.00mm | Plated | None
4 | 3.20mm | Plated | None
45 Total

SpaceLab - Federal University of Santa Catarina

Project: Interstage Interface Panel Nº1

Title: Layer stack and drill tables

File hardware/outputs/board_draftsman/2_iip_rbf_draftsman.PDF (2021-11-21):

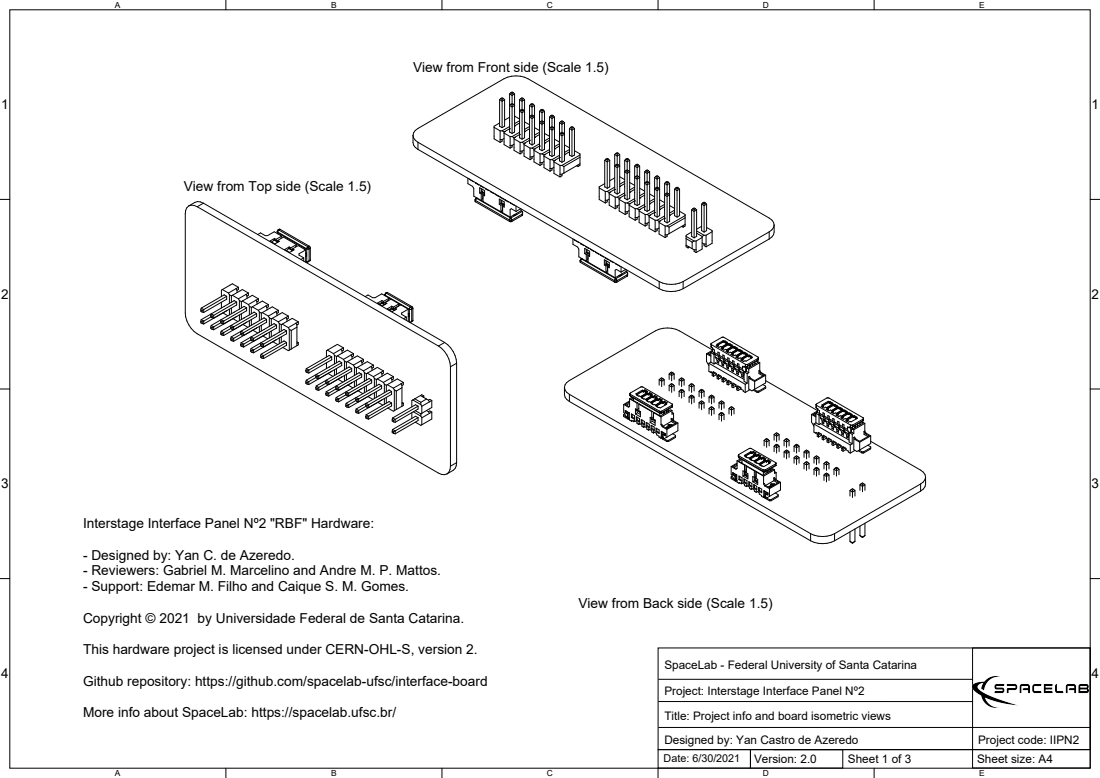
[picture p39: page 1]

View from Front side (Scale 1.5)

View from Top side (Scale 1.5)

Interstage Interface Panel Nº2 "RBF" Hardware:

- Designed by: Yan C. de Azeredo.
- Reviewers: Gabriel M. Marcelino and Andre M. P. Mattos.
- Support: Edemar M. Filho and Caique S. M. Gomes.

View from Back side (Scale 1.5)

Copyright © 2021 by Universidade Federal de Santa Catarina.

This hardware project is licensed under CERN-OHL-S, version 2.

SpaceLab - Federal University of Santa Catarina

Github repository: https://github.com/spacelab-ufsc/interface-board

Project: Interstage Interface Panel Nº2

More info about SpaceLab: https://spacelab.ufsc.br/

Title: Project info and board isometric views
Designed by: Yan Castro de Azeredo

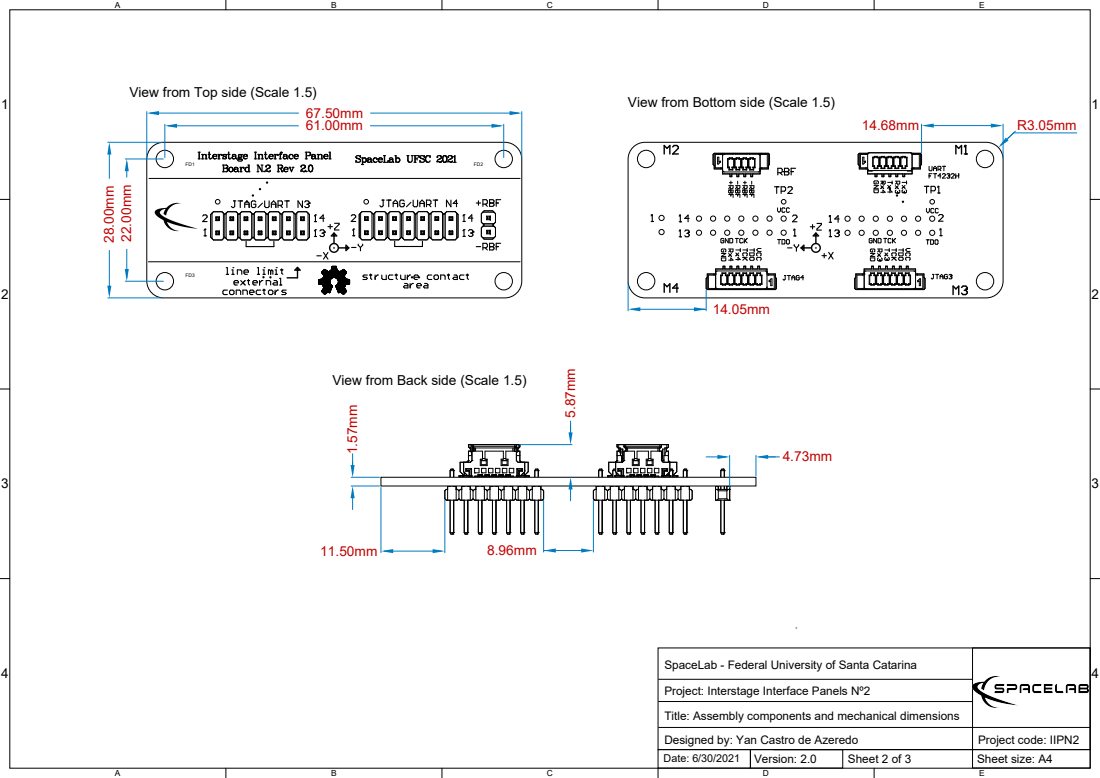
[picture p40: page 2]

View from Top side (Scale 1.5)

View from Bottom side (Scale 1.5)

View from Back side (Scale 1.5)

SpaceLab - Federal University of Santa Catarina

Project: Interstage Interface Panels Nº2

Title: Assembly components and mechanical dimensions

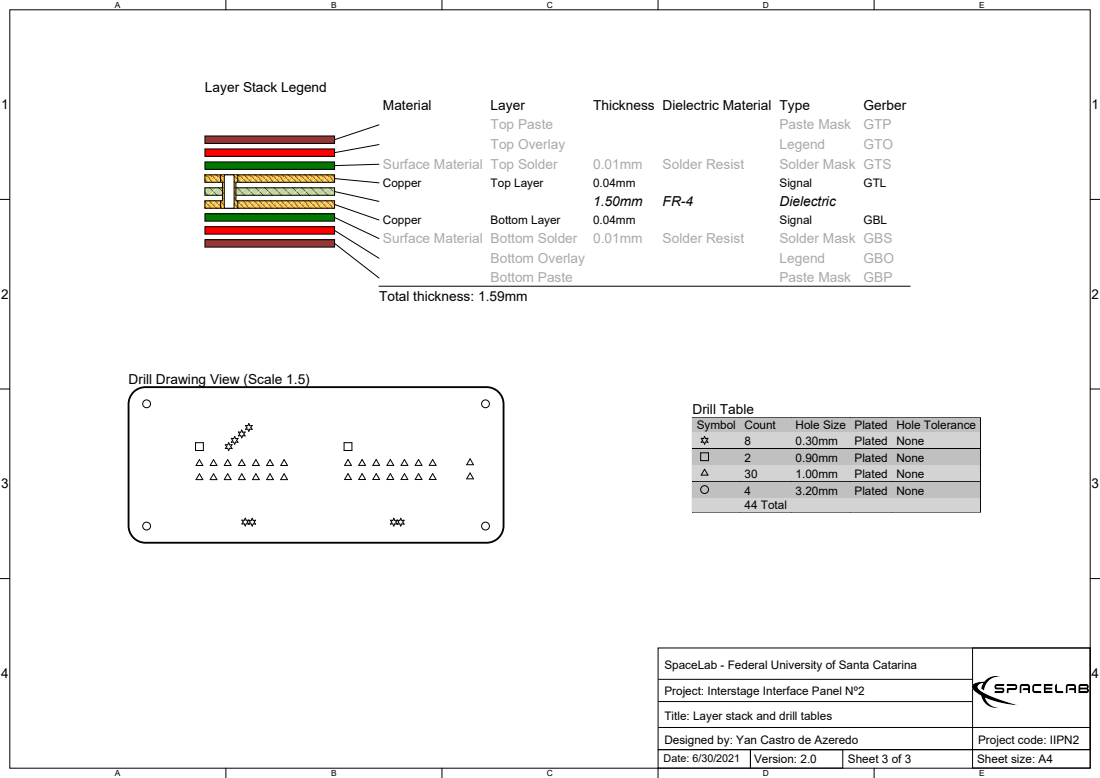
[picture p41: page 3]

Drill Drawing View (Scale 1.5)

Symbol | Count | Hole Size | Plated | Hole Tolerance

8 | 0.30mm | Plated | None
2 | 0.90mm | Plated | None
30 | 1.00mm | Plated | None
4 | 3.20mm | Plated | None
44 Total

SpaceLab - Federal University of Santa Catarina

Project: Interstage Interface Panel Nº2

Title: Layer stack and drill tables

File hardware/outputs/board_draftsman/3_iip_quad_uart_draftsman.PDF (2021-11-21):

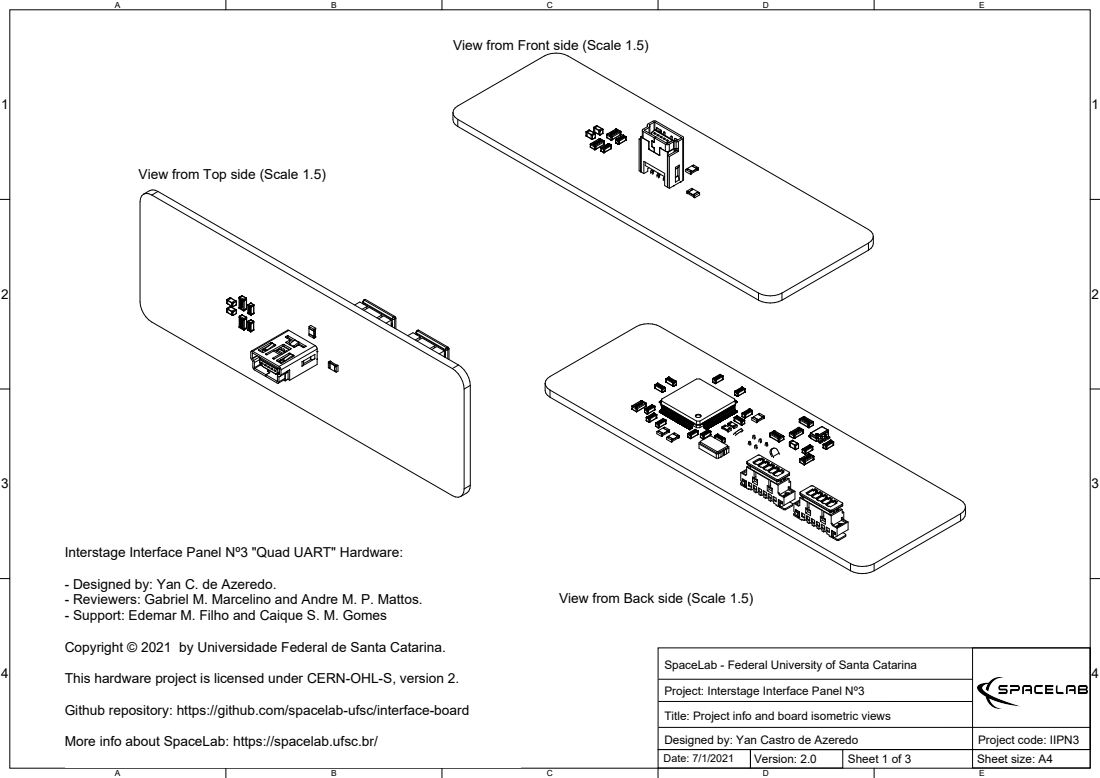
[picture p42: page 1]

View from Front side (Scale 1.5)

View from Top side (Scale 1.5)

Interstage Interface Panel Nº3 "Quad UART" Hardware:

- Designed by: Yan C. de Azeredo.
- Reviewers: Gabriel M. Marcelino and Andre M. P. Mattos.
- Support: Edemar M. Filho and Caique S. M. Gomes

View from Back side (Scale 1.5)

Copyright © 2021 by Universidade Federal de Santa Catarina.

SpaceLab - Federal University of Santa Catarina

This hardware project is licensed under CERN-OHL-S, version 2.

Project: Interstage Interface Panel Nº3

Github repository: https://github.com/spacelab-ufsc/interface-board

Title: Project info and board isometric views
Designed by: Yan Castro de Azeredo

More info about SpaceLab: https://spacelab.ufsc.br/

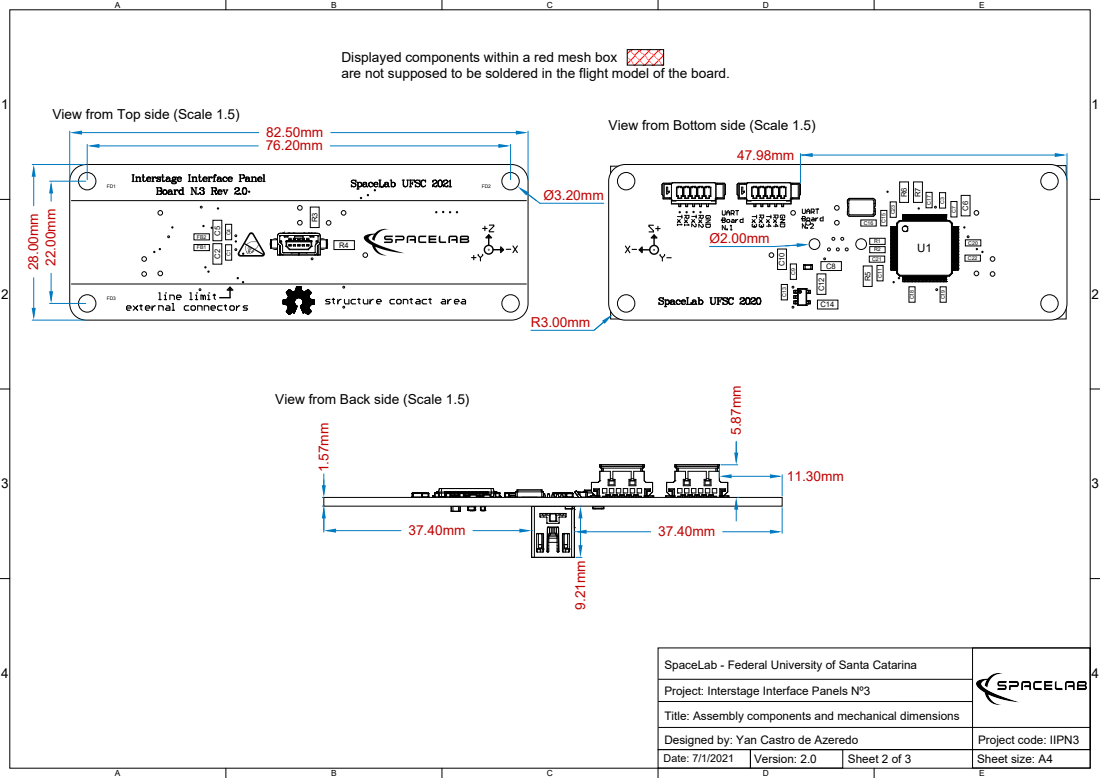
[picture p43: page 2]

Displayed components within a red mesh box
are not supposed to be soldered in the flight model of the board.

View from Top side (Scale 1.5)

View from Bottom side (Scale 1.5)

View from Back side (Scale 1.5)

SpaceLab - Federal University of Santa Catarina

Project: Interstage Interface Panels Nº3

Title: Assembly components and mechanical dimensions

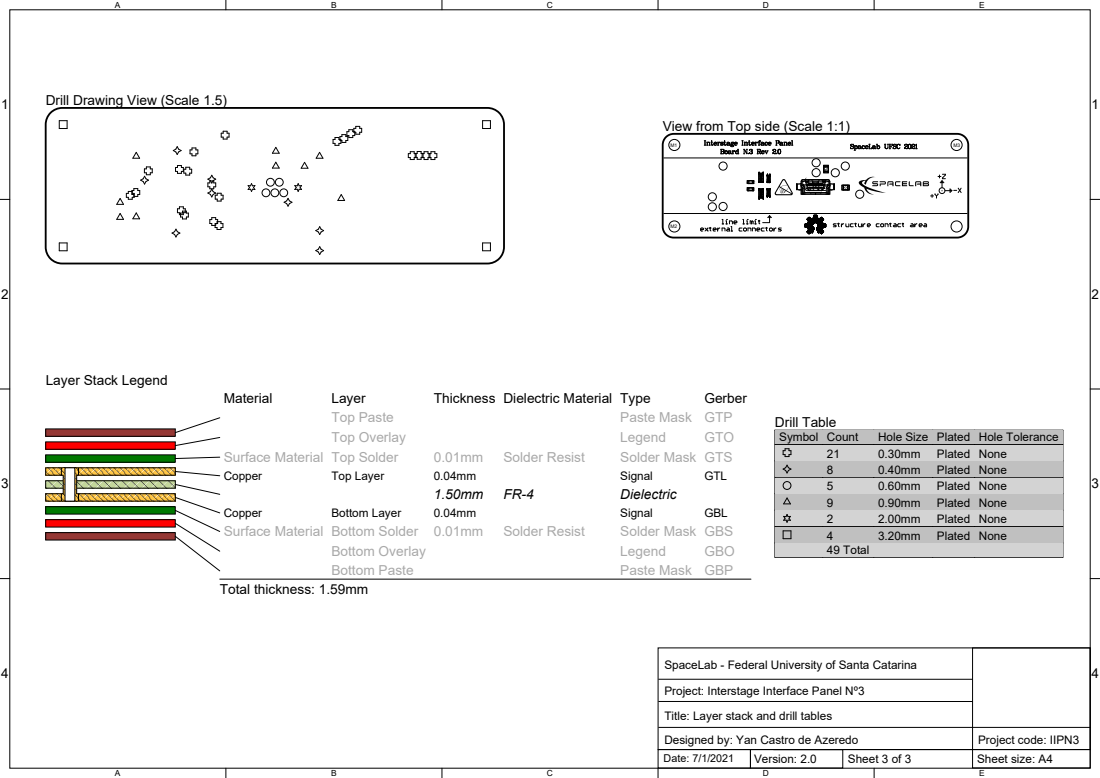
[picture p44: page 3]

Drill Drawing View (Scale 1.5)

View from Top side (Scale 1:1)

Symbol | Count | Hole Size | Plated | Hole Tolerance

21 | 0.30mm | Plated | None
8 | 0.40mm | Plated | None
5 | 0.60mm | Plated | None
9 | 0.90mm | Plated | None
2 | 2.00mm | Plated | None
4 | 3.20mm | Plated | None
49 Total

SpaceLab - Federal University of Santa Catarina

Project: Interstage Interface Panel Nº3

Title: Layer stack and drill tables

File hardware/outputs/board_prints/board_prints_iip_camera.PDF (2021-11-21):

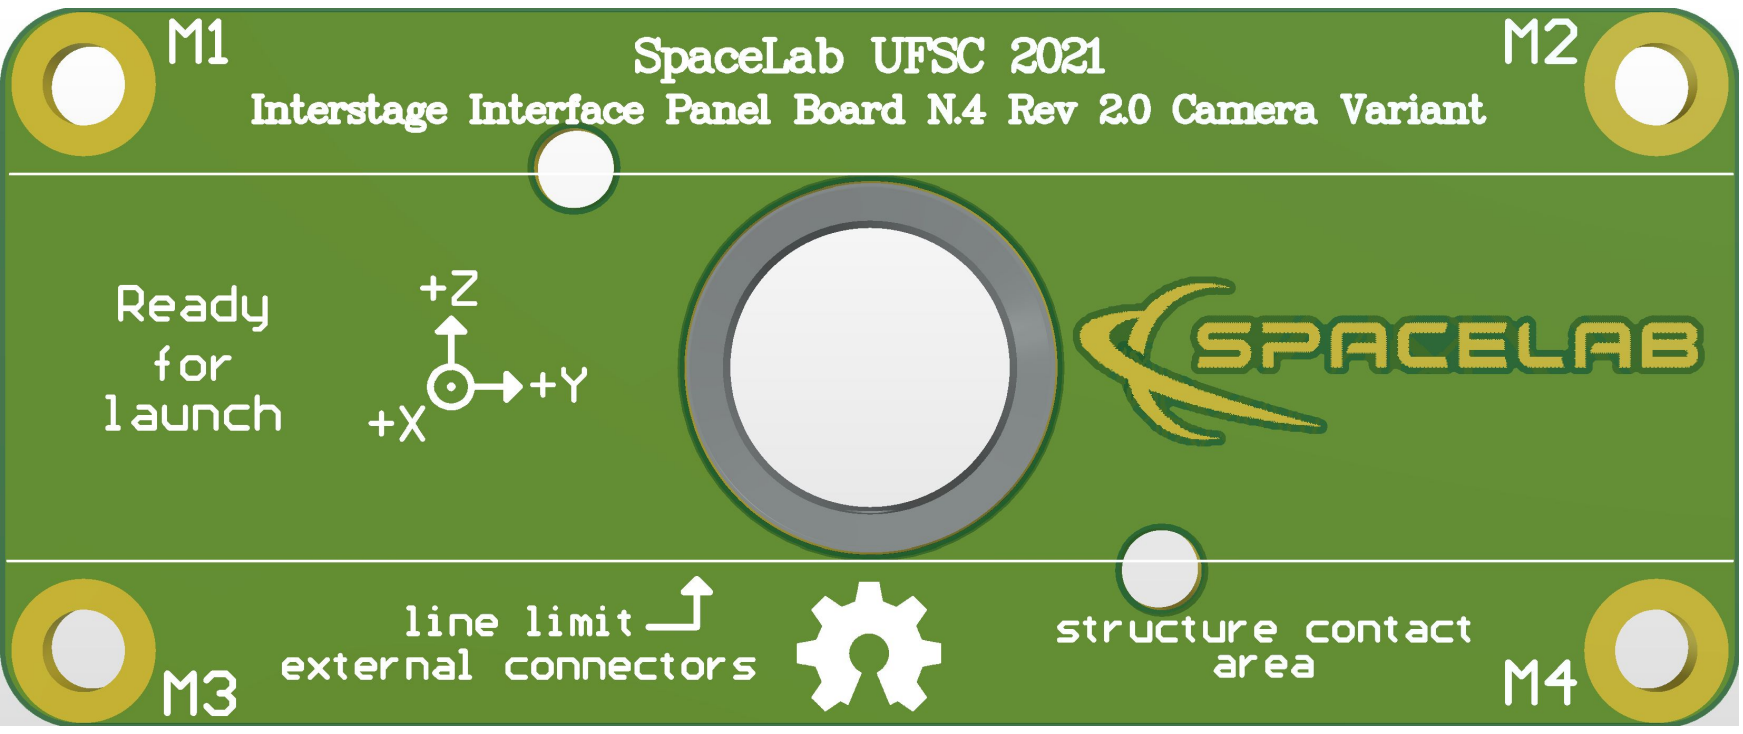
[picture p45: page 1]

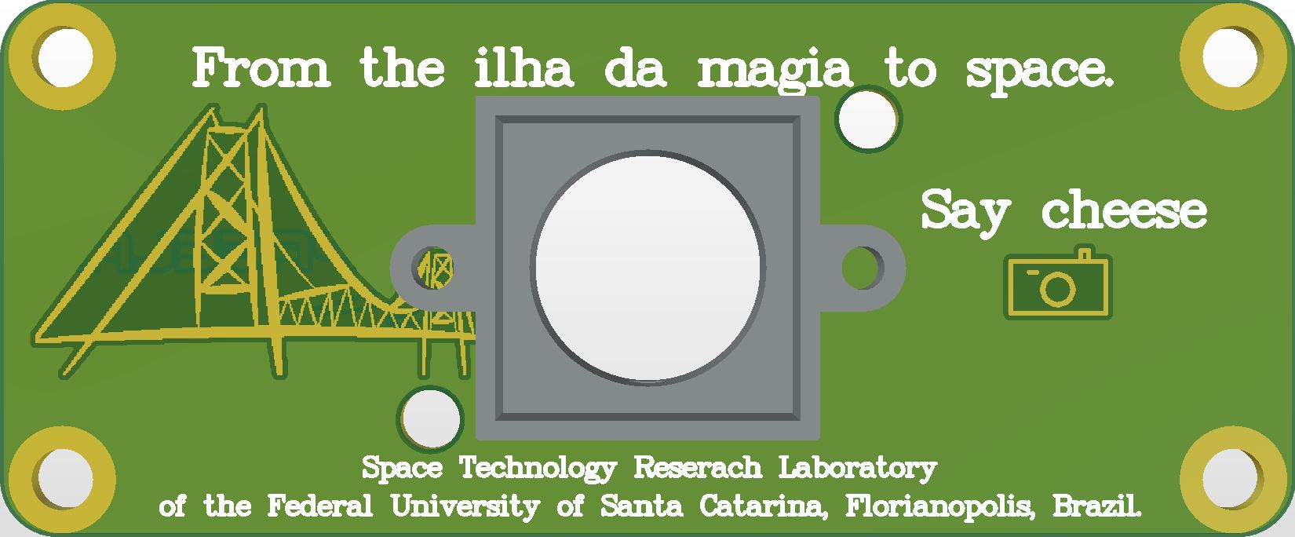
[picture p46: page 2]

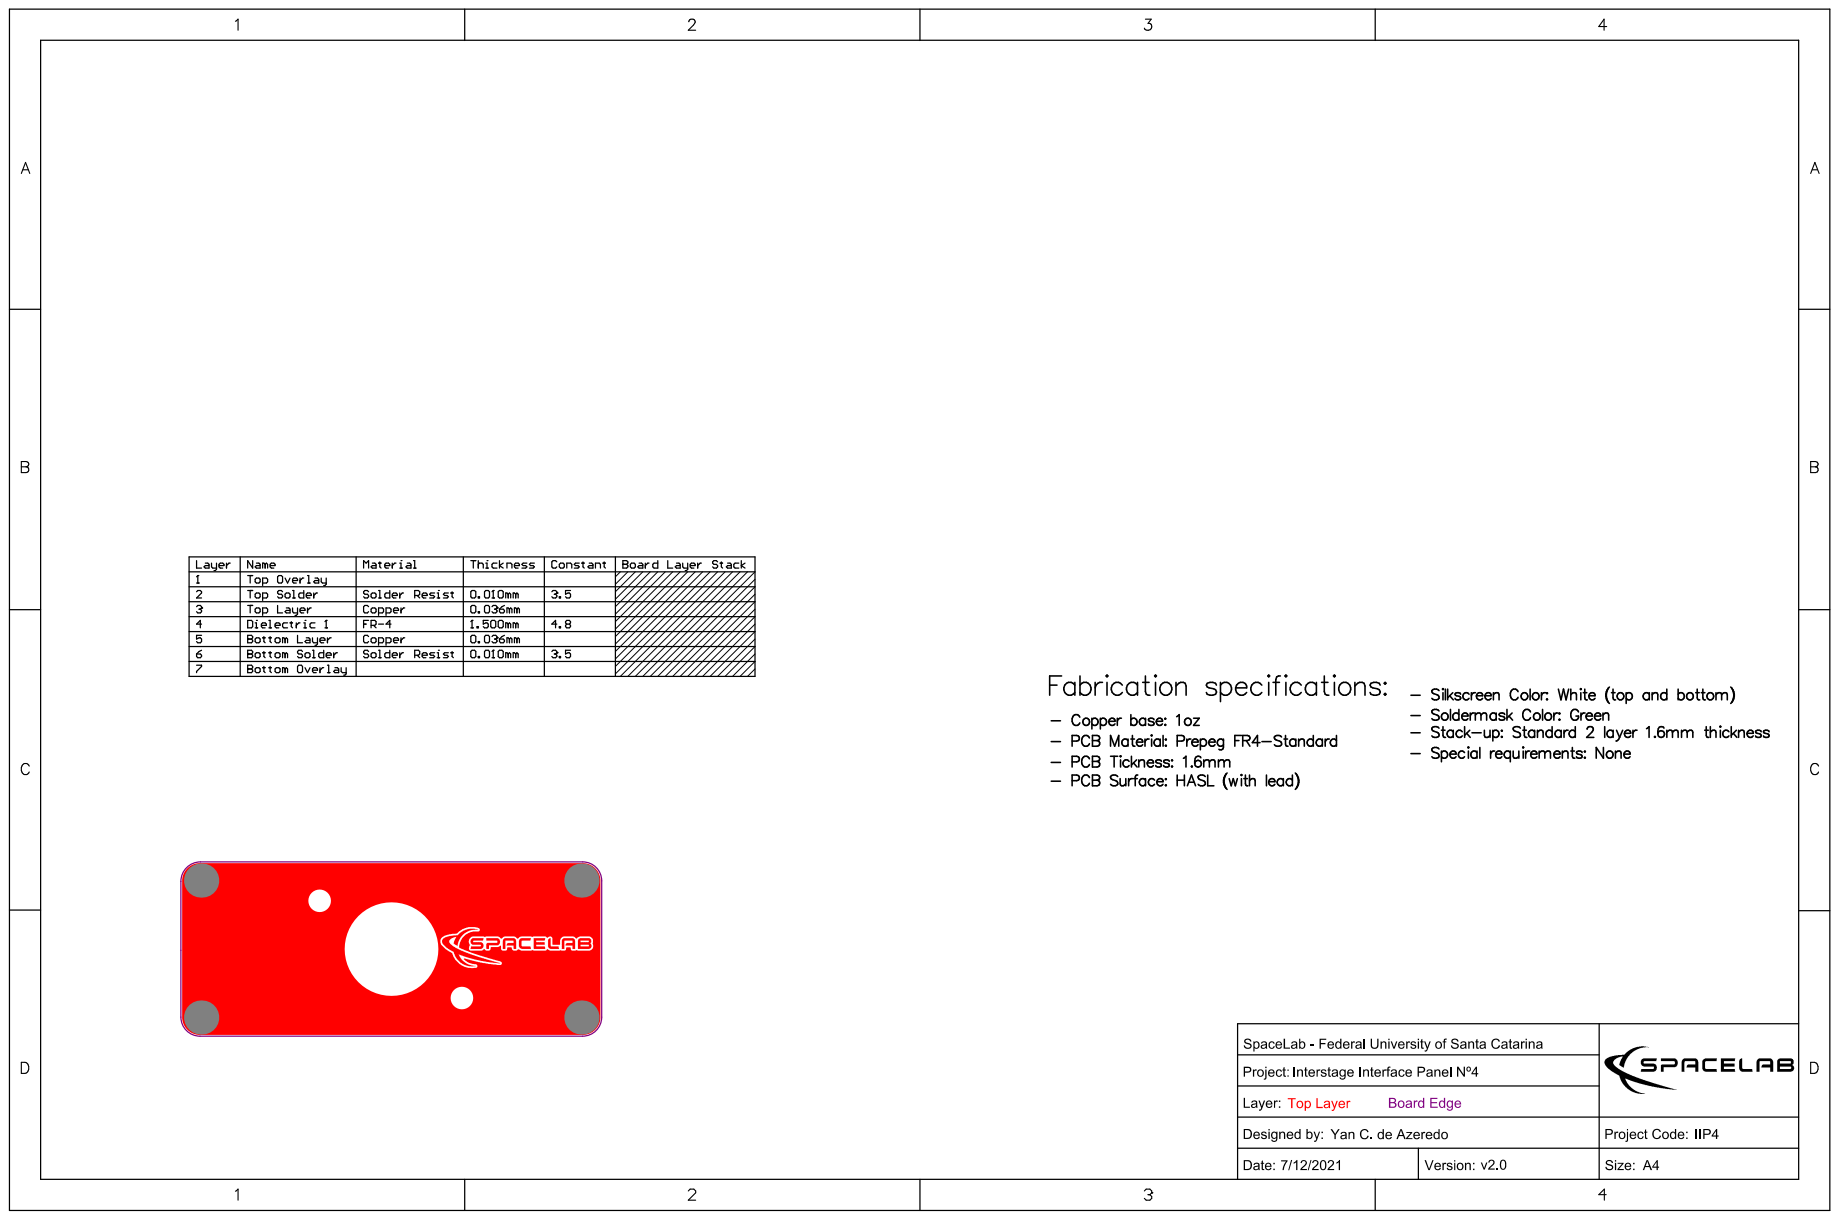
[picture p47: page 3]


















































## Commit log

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2020-04-17 Semi USB: Reorganizing the directory structure considering separeate projects for each pcb board and initial drawings
    [0_Architecture.SchDoc, 1_Interface_QuadUART.PcbDoc, 1_Interface_QuadUART.PrjPCB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]
2020-04-17 Semi USB: Relocating 0_Architecture shematic used in all semi usb board projects
    [0_Architecture.SchDoc]
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2020-04-25 Semi USB: schematic: Done initial drawing of jtag and batterie charge interface board #10
    [2_Interface_JTAG.SchDoc]
2020-04-28 Semi USB: Deleted PCB Design Checklist present in Source of all boards directory and added the file for each pcb project tree
    [PCB Design Checklist.xlsx]
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2020-04-30 Semi USB: Schematic: Added RBF and 9 pin PicoBlade connector for reciving UART from 1_Interface_QuadUART board #10
    [2_Interface_JTAG.SchDoc]
2020-04-30 Semi USB: layout: Initial component positioning and board size definition for 2_Interface_JTAG PCB #11
    [Interfac_JTAG.PcbDoc]
2020-04-30 Semi USB: Renaming "Interfac_JTAG.PcbDoc" to "2_Interface_JTAG.PcbDoc" and adding to project file #11
    [2_Interface_JTAG.PcbDoc, 2_Interface_JTAG.PrjPCB]
2020-04-30 Semi USB: Checklist: Updating PCB Design Checklist with initial observations and comments for 2_Interface_JTAG
    [PCB Design Checklist.xlsx]
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2020-05-04 Semi USB: schematic: Removed RBF and charging batteries headers from 2_Interface_JTAG sheet #10
    [2_Interface_JTAG.SchDoc]
2020-05-04 Semi USB: schematic: layout: Added the initial schematics and pcb files for the third board design (3_Interface_Charge_RBF) #12 #13
    [3_Interface_Charge_RBF.PcbDoc, 3_Interface_Charge_RBF.PrjPCB, 3_Interface_Charge_RBF.SchDoc]
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2020-05-04 Semi USB: layout: Added mechanical mouting holes and its initial positioning for 2_Interface_JTAG PCB #11
    [2_Interface_JTAG.PcbDoc]
2020-05-06 Semi USB: schematic: Adding a bit of more information to 3_Interface_Charge_RBF schematic sheet #12
    [3_Interface_Charge_RBF.SchDoc]
2020-05-06 Semi USB: layout: Done the initial PCB layout for the 3_Interface_Charge_RBF board #13
    [3_Interface_Charge_RBF.PcbDoc]
2020-05-06 Semi USB: layout: Repositioning mechanical mouting holes and done experimental pin headers positioning with MSP-FET couterpart #11
    [2_Interface_JTAG.PcbDoc]
2020-05-07 Semi USB: libraries: Fixing inconsistencies between schematic and pcb models (picoblades housing 0 designator) and adding 5 position PicoBlade header to libraries
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2020-05-07 Semi USB: schematic: Removing JTAGs and PicoBlades 1 and 2 from schematic and adding new header for UART interface with FT4232H #10
    [2_Interface_JTAG.SchDoc]
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2020-05-07 Semi USB: layout: Removed JTAG headers 1 and 2 from pcb document 2_Interface_JTAG and done initial components positioning #11
    [2_Interface_JTAG.PcbDoc]
2020-05-07 Semi USB: Renamed directory and all files associated with "3_Interface_Charge_RBF" to "1_Interface_Charge_RBF" #12 #13
    [1_Interface_Charge_RBF.PcbDoc, 1_Interface_Charge_RBF.PrjPCB, 1_Interface_Charge_RBF.SchDoc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]
2020-05-07 Semi USB: Renamed directory and all files associated with "1_Interface_QuadUART" to "3_Interface_QuadUART" #9
    [1_Interface_QuadUART.SchDoc, 3_Interface_QuadUART.PcbDoc, 3_Interface_QuadUART.PrjPCB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]
2020-05-07 Semi USB: Refreshing 1_Interface_Charge_RBF project file with the new renamed associated files
    [1_Interface_Charge_RBF.PrjPCB]
2020-05-07 Semi USB: Refreshing 3_Interface_QuadUART project file with the new renamed associated files
    [3_Interface_QuadUART.PrjPCB]
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2020-05-08 Semi USB: schematic: Redraw schematic of first board 1_Interface_Charge_RBF, considering now two headers for msp-fet debugger alongside RBF, charge headers and test points #12
    [1_Interface_Charge_RBF.SchDoc]
2020-05-08 Semi USB: layout: Updating PCB document of 1_Interface_Charge_RBF including 2 headers for msp-fet debbuger, repositioned components for first mechanical evaluation #13
    [1_Interface_Charge_RBF.PcbDoc]
2020-05-08 Semi USB: Adding parameters for 1_Interface_Charge_RBF project file (drawer name, model and revision)
    [1_Interface_Charge_RBF.PrjPCB]
2020-05-08 Semi USB: checklist: Adding PCB Design Checklist for 1_Interface_Charge_RBF project and updated the schematic section within checklist
    [PCB Design Checklist.xlsx]
2020-05-08 Semi USB: schematic: Redrawed 2_Interface_JTAG to include new graphic caracteristics of components, test points and more info #10
    [2_Interface_JTAG.SchDoc]
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2020-05-08 Semi USB: Adding parameters for 2_Interface_JTAG project file (drawer name, model and revision)
    [2_Interface_JTAG.PrjPCB]
2020-05-08 Semi USB: layout: Updating PCB document of 2_Interface_JTAG with latest redrawed schematic for first mechanical evaluation #11
    [2_Interface_JTAG.PcbDoc]
2020-05-08 Semi USB: checklist: Updated some itens on PCB Design Checklist schematic section for 2_Interface_JTAG project
    [PCB Design Checklist.xlsx]
2020-05-08 Semi USB: output: Generating .step files for latest 1_Interface_Charge_RBF and 2_Interface_JTAG PCBs #14
    [1_Interface_Charge_RBF.step, 2_Interface_JTAG.step]
2020-05-12 Removing README files with git mistakes and step and parasolid models with no mechanical holes
    [1_Interface_Charge_RBF.step, 2_Interface_JTAG.step]
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2020-05-19 Semi USB: layout: Updated 1_Interface_Charge_RBF PCB for zero errors in DRC #13
    [1_Interface_Charge_RBF.PcbDoc]
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2020-05-22 Semi USB: layout: Fixing mechanical holes positioning and origin in 2_Interface_JTAG board #11
    [2_Interface_JTAG.PcbDoc]
2020-05-23 Semi USB: schematic: Fixed order of Tx4 and Rx4 signals net labels in picoblade pins #10
    [2_Interface_JTAG.SchDoc]
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2020-05-23 Semi USB: layout: Fixed non-linear bottom shape of PCB #11
    [2_Interface_JTAG.PcbDoc]
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2020-05-23 Semi USB: libraries: Fixing JTAG pin header 3D model positioning and adding Picoblade header counterparts
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2020-05-24 Semi USB: layout: Repositioned 5 pos UART Picoblade header to the other side of the board to avoid mechanical conflic with 1_Interface_Charge_RBF #11
    [2_Interface_JTAG.PcbDoc]
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2020-05-28 Semi USB: schematic: Fixing pin polarity issues in picoblades, RBF and Charge Batteries headers #12
    [1_Interface_Charge_RBF.SchDoc]
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2020-05-29 Semi USB: layout: Updating top and bottom silkcreen labels, fixing Design Rule Check errors and removing dead copper from top and bottom GND planes #13
    [1_Interface_Charge_RBF.PcbDoc]
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2020-05-29 Semi USB: libraries: Adding missing crosshair in assembly drawing layer for JST charger header
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2020-06-01 Semi USB: schematic: Fixing inverted SBW pins in picoblade headers in 2_Interface_JTAG schematic #10
    [2_Interface_JTAG.SchDoc]
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2020-06-10 Semi USB: layout_info: Adding missing "Sheet" representation on mechanical layer 16 on N1 board
    [1_Interface_Charge_RBF.PcbDoc]
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2020-06-19 Semi USB: schematic: Drawed data lines and optional 0805 pad for noise/EMC reduction betwem USB shield and signal ground #9
    [3_Interface_QuadUART.SchDoc]
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2020-06-19 Semi USB: schematic: Drawed the circuits for rest of the IC pins considering a non-EEPROM project and removing wrong pull-downs in PWREN# (output) and RI# (input) pins #9
    [3_Interface_QuadUART.SchDoc]
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2020-06-21 Semi USB: schematic: Adding extra test points to power and reference pins of FT4232H and placing missing GND connection on crystal oscillator pins #9
    [3_Interface_QuadUART.SchDoc]
2020-06-21 Semi USB: schematic: Updating components designators, positioning and fixing differential pair wiring in USB data lines #9
    [3_Interface_QuadUART.SchDoc]
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2020-06-21 Semi USB: schematic: Adding missing revision version and more one reviewer to architecture sheet #6
    [0_Architecture.SchDoc]
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2020-06-21 Semi USB: schematic: Adding missing differential pair directive on the USB_RX_N and USB_RX_P nets #9
    [3_Interface_QuadUART.SchDoc]
2020-06-28 semi USB: libraries: Improving comments, fixing footprints on resistors and adding 10 ohms resistor to schematic library
2020-06-28 Semi UBS: libraries: Adding missing footprint for 0603 resistors
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2020-06-29 Semi USB: layout: Removed RBF pin header from N1 board and moved to N2 board PCB layout, fixed fiducials and picoblade headers positioning closes #26 #27 #28
    [1_Interface_Charge_RBF.PcbDoc, 2_Interface_JTAG.PcbDoc]
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2020-07-01 Semi USB: 3D models: Adding missing models for JTAG pin headers and compatible MSP-FET connector counterpart
    [61201423021_MSP-FET_compatible_connector.stp, m20-9980745_asm.stp]
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2020-07-01 Semi USB: "bug fix": Fixing missing paramenters from importated 4 pin picoblade and refreshing project files for N1 board
    [1_IIP_Charge.PcbDoc, 1_IIP_Charge.PrjPCB, 1_IIP_Charge.SchDoc]
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2020-07-02 Semi USB: pcb info: layout: Ajusting sheet layer position, correcting text in dimension layer and importing new parameters in schematic to PCB #11
    [2_Interface_JTAG.PcbDoc]
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2020-07-02 Semi USB: pcb info: Adding missing date and changing "ENIG" to "HASL" PCB surface specification on N.2 board pcb document "sheet" layer
    [2_IIP_RBF.PcbDoc]
2020-07-02 Semi USB: architecture: Fixing typo "Fidutials" #9
    [0_Architecture.SchDoc]
2020-07-02 Semi USB: schematic: Fixing typo "reduntant"
    [2_IIP_RBF.SchDoc]
2020-07-02 Semi USB: pcb info: Fixing typo "Tickness"
    [1_IIP_Charge.PcbDoc, 2_IIP_RBF.PcbDoc]
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2020-07-03 Semi USB: output: Updating PDF file of N.1 board with minor corrections to typos #30
2020-07-03 Semi USB: layout: Fixing tracks with DRC errors according to 2 layer JLCPCB manufacture capability #11
    [2_IIP_RBF.PcbDoc]
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2020-07-05 Semi USB: schematic: Fixing net label name "3V3" to "3.3V" in VPLL and VPHY circuit #9
    [3_Interface_QuadUART.SchDoc]
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2020-07-12 Semi USB: libaries: Fixing square to round shape pads of vertical USB connector for more pratical manufacturing
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2020-07-15 Semi USB: libraries: Fixing footprints of usb connector and crystal according to their datasheets
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2020-07-15 Semi USB: layout: fixed blocked fiducial by picoblade connector on bottom layer and redrawed tracks for UART signals #15
    [3_IIP_QuadUART.PcbDoc]
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2020-08-14 Semi USB: doc: figures: Fixing gray line in bottom of the image of Nº1 board perspective view
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2020-12-15 doc: chapters: Adding missing information about board names used on PCBs source files on system overview chapter
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2020-12-22 doc: header: Small fixes to initial commentaries and added 1.0v release to version control table
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2021-06-29 hardware: sources: Fixing board edge text layer indicator
    [1_iip_charge.PcbDoc, 2_iip_rbf.PcbDoc]
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2021-06-29 hardware: fabrication: Updating IIP Nº1, Nº2 and Nº3 fabrications files, adding new files for IIP Nº4 closure and camera and missing individual BOMs #65
    [board_bom_1_iip_charge.xlsx, board_bom_2_iip_rbf.xlsx, board_bom_3_iip_quad_uart.xlsx]
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2021-07-12 hardware: Fixing board print size to A4 #65

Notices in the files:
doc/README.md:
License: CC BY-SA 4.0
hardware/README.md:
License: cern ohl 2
